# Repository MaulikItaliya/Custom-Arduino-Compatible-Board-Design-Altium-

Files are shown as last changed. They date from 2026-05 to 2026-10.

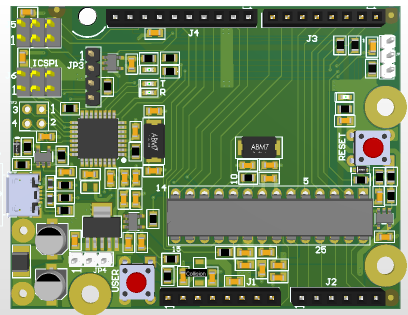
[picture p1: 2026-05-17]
!Released Files/Step 2 - Board Assembly/Variant 2 - 28Pins V1.1-5V and 3V3/3D Model - 28Pins V1.1 - 5V and 3.3V.png

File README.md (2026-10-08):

# Arduino Compatible 28-Pin Development Board

## Overview
Custom Arduino-compatible PCB designed in Altium Designer.

Features:
- ATmega328P-based design
- USB/UART programming
- 5V and 3.3V variants
- Through-hole + SMD support
- 2-layer PCB 

## Tools Used
- Altium Designer
- Gerber Generation
- Assembly Drawings
- BOM Export

## Repository Structure
/docs
/hardware
/manufacturing
/images

## Variants
### Variant 1
Fixed 5V version

### Variant 2
5V + 3.3V selectable version

## Manufacturing Files
Gerber, drill, BOM, pick-and-place, and assembly outputs included.

## Images


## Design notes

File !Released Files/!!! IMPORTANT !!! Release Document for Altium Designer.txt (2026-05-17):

Follow this procedure before releasing files. Confirm every action with your initials and date.
IF ANY CHANGES NEEDS TO BE DONE, START THE PROCEDURE FROM BEGINNING!

The procedure needs to be executed in order as defined here. Start from number 1
--------------------------------------------------------------------------------

1) Right Click on the project -> Compile PCB project
I confirm, the project compiles with no errors: 
YourIntials [15-05-2026]

2) Run Design -> Update PCB Document
I confirm, there are no differences between Schematic and PCB: 
 [15-05-2026]

3) Impedance
I confirm, I have updated and check track width/gap to match required impedance (e.g 55 OHMs): 
NA

4) Run Tools -> Polygon Pours -> Rebuild All
I confirm, all polygons have been repoured: 
 [15-05-2026]

5) Run Tools -> Design Rule Check -> Run Design Rule Check
I confirm, I have checked Design Rule Output File:
 [15-05-2026]

6) Gerber check
I confirm, I have copied and visually checked gerber files placed in \PCB Manufacturing\Gerber Output\
 [15-05-2026]

7) Other files
I confirm, I have copied and checked files placed in subdirectories:
YourIntials [DAY-MONTH-YEAR]

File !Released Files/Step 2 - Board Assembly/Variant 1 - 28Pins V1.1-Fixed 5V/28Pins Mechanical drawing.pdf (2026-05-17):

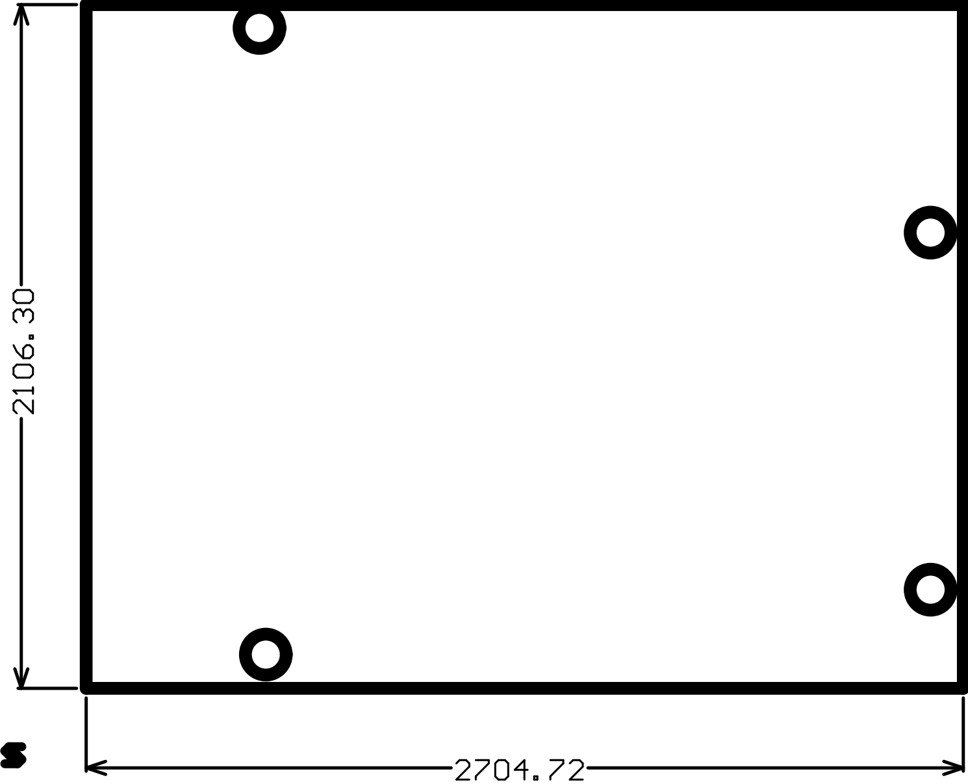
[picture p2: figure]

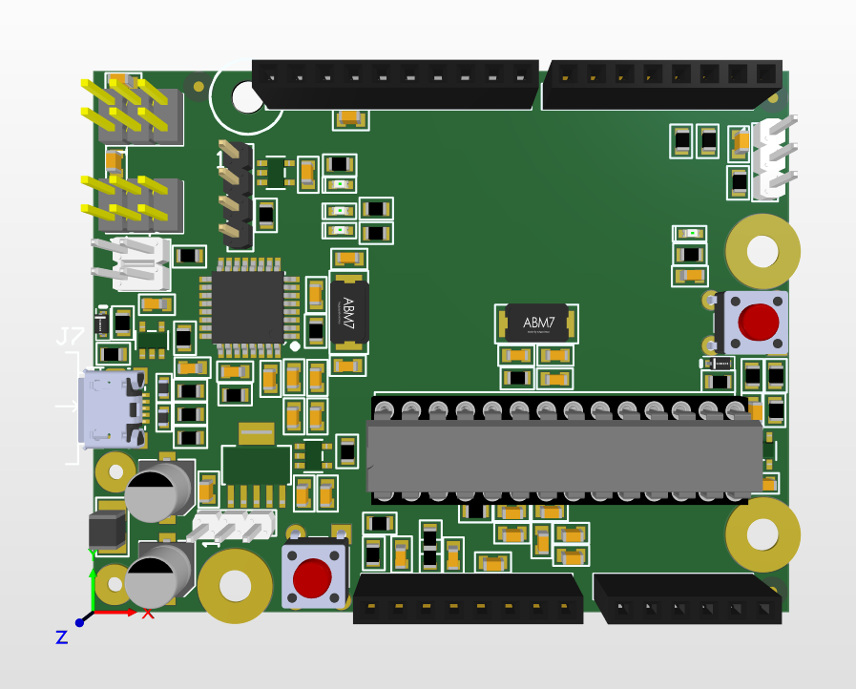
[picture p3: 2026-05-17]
images/Screenshot 2026-04-12 070946.png

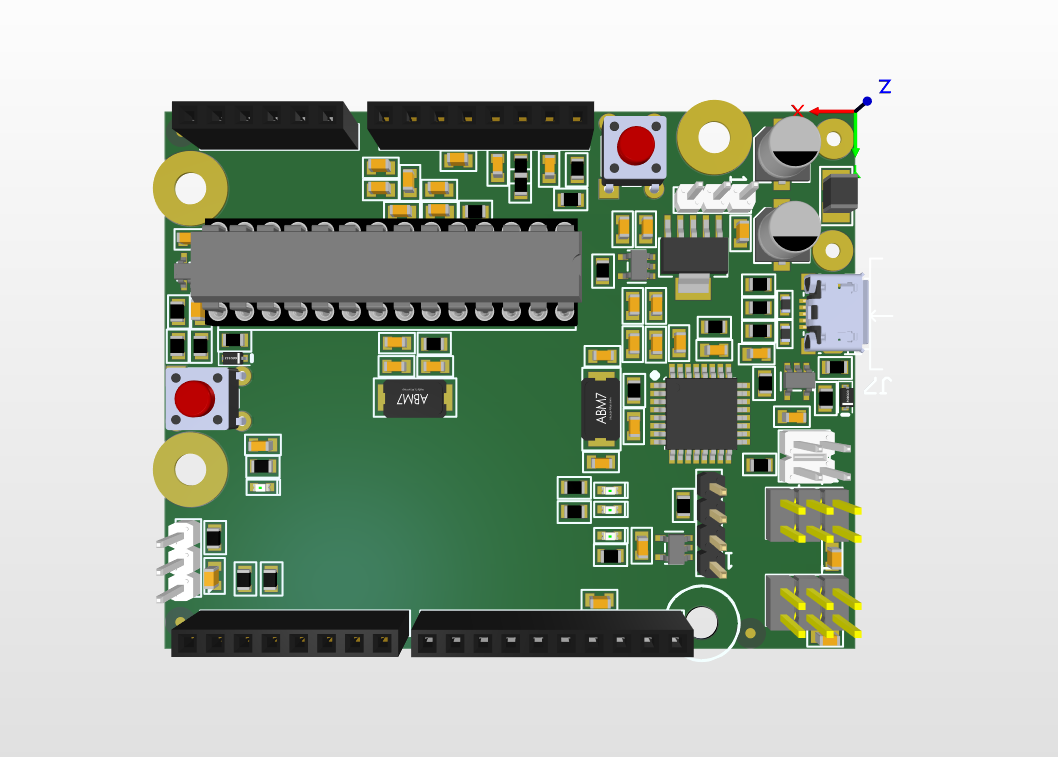
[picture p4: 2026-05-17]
images/Screenshot 2026-04-13 221038.png

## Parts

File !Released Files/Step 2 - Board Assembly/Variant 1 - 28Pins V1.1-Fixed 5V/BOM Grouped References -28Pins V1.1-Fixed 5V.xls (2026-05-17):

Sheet: Part List Report
 | Component reference list (grouped) |  |  |  | 28Pins
 | Source Data From: |  | ardino.PrjPcb |  |  | Contact: |  | Generated by:
 | Project: |  | ardino.PrjPcb
 | Variant: |  | FIXED 5V |  |  |  |  | FEDEVEL
 | Report Date: |  | 16-05-2026 | 10:37 |  |  |  | http://www.fedevel.com
 | Print Date: |  | 2026-05-16 | 10:38:30
# | Designator | Quantity | Comment | Description | #Column Name Error:' Manufacturer 1 | #Column Name Error:' Manufacturer Part Number 1 | #Column Name Error:' Package / Case | #Column Name Error:' Supplier 1 | #Column Name Error:' Supplier Part Number 1
1 | C1, C2 | 2 | 100uF/10V | Cap Aluminum Polymer 100uF 10VDC 20% (7.3 X 4.3 X 1.9mm) SMD 0.04 Ohm 3200mA 2000h 105C T/R
2 | C3, C12, C13, C19, C21, C22 | 6 | 10uF/16V | 16V 10uF X5R 卤10% 0805 Multilayer Ceramic Capacitors MLCC - SMD/SMT ROHS
3 | C4, C5, C6, C8, C11, C14, C15, C16, C17, C20, C23, C24, C26, C28, C29, C30, C31, C32, C33, C34 | 20 | 100nF | Ceramic capacitor, 100 nF, 50 V (DC), ±10 %, SMD 0805 (2012), X7R, C2012X7R1H104K085AA
4 | C7 | 1 | 1uf | 25V 1uF X5R 卤20% 0805 Multilayer Ceramic Capacitors MLCC - SMD/SMT ROHS
5 | C9, C10, C25, C27 | 4 | 18pF | Multilayer Ceramic Capacitors MLCC - SMD/SMT 50V 18pF C0G 0805 2%
6 | D1 | 1 | Green | LED Uni-Color Green 572nm Automotive 2-Pin Chip 0603(1608Metric) T/R
7 | D2, D3, D4 | 3 | Orange | LED Uni-Color Orange 610nm Automotive 2-Pin Chip 0603(1608Metric) T/R
8 | D5, D6 | 2 | BAT54HT1G | Small Signal Schottky Diode, Single, 30 V, 200 Ma, 800 Mv, 600 Ma, 150 C
9 | FB1, FB2, FB3 | 3 | MPZ2012S601AT000 | Ferrite Beads Multi-Layer Power 600Ohm 25% 100MHz 2A 100mOhm DCR 0805 T/R
10 | J1, J3 | 2 | HDR FEMALE 1x8 2.54mm | 2.54mm (0.1) Pitch SIL Vertical PC Tail Socket Assembly, selective gold + tin, 8 contacts"
11 | J2 | 1 | HDR_1x6_2.54mm | Conn Socket Strip Receptacle 6 Position 2.54mm Solder Straight Through Hole Tube
12 | J4 | 1 | M20-7821046 | Conn Socket Strip Receptacle 10 Position 2.54mm Solder Straight Through Hole Tube
13 | J5, J6 | 2 | HDR_2X3 | Conn Unshrouded Header HDR 6 POS 2.54mm Solder ST Top Entry Thru-Hole BergStik® Bag
14 | J7 | 1 | 10118193-0001LF | USB - micro B USB 2.0 Receptacle Connector 5 Position Surface Mount, Right Angle, Horizontal
15 | JP1 | 1 | HDR_1x3 | Pin Header, Board-to-Board, 2.54 mm, 1 Rows, 3 Contacts, Through Hole, FCI BergStik II 68000
16 | JP3 | 1 | HDR_x4 | Conn Unshrouded Header HDR 4 POS 2.54mm Solder ST Top Entry Thru-Hole BergStik® Bulk
17 | L1 | 1 | 2u2 / 2A | General Purpose Inductor, 2.2uH, 20%, 1 Element, Ferrite-Core, SMD, 1210
18 | Link1, Link2 | 2 | Link | 2 Position 2.54 mm Centerline Single Circuit Open Top Jumper
19 | R1 | 1 | 100k | 125Mw Thick Film Resistors 100Ppm/ 1% 100K 0805 Chip Resistor Surface Mount Rohs
20 | R2, R3, R15, R17, R22 | 5 | 560 | Fixed Resistor, Metal Glaze/thick Film, 0.125W, 560ohm, 150V, 1% +/-Tol, 100ppm/Cel, Surface Mount, 0805
21 | R4, R14, R18, R19, R20, R21 | 6 | 10k | Res Thick Film 0805 10K Ohm 1% 0.125W(1/8W) +/-100ppm/C Epoxy Pad SMD T/R
22 | R5, R6, R7, R13, R23, R24, R25 | 7 | 22R | 125mW Thick Film Resistors 150V ±100ppm/℃ ±1% 22Ω 0805 Chip Resistor - Surface Mount ROHS
23 | R8, R27 | 2 | 0 | GENERAL PURPOSE CHIP RESISTOR Metal Glaze/thick Film, 0.125W, 0ohm, Surface Mount, 0805
24 | R9, R16 | 2 | 1M | Res Thick Film 0805 1M Ohm 1% 0.125W(1/8W) ±100ppm/C Pad SMD T/R Automotive AEC-Q200
25 | R10, R11, R12 | 3 | 1k | Res Thick Film 0805 1K Ohm 1% 0.125W(1/8W) ±100ppm/C Pad SMD T/R
26 | SCKT FOR U1 | 1 | 28-DIP Socket | IC Socket, DIP28, 28 Contact(s), 2.54mm Term Pitch, 7.62mm Row Spacing, Solder
27 | SW1, SW2 | 2 | 1825910-6 | Switch Tactile OFF (ON) SPST Round Button PC Pins 0.05A 24VDC 1.57N Thru-Hole Loose
28 | U1 | 1 | ATMEGA328P-PU | Microchip - ATMEGA328P-PU - Microcontroller Mcu, 8 Bit, Atmega, 20MHZ, DIP-28
29 | U2 | 1 | ATMEGA16U2-AU | Risc Microcontroller, 8-BIT, Flash, AVR Risc Cpu, 16MHZ, Cmos, PQFP32
30 | U3 | 1 | TL1963A-33DCQR | LDO Regulator Pos 3.3V 1.5A 6-Pin(5+Tab) SOT-223 T/R
31 | U4, U5, U6, U7 | 4 | SN74AHC1G09DBVR | 1-ch, 2-input 2-V to 5.5-V high-speed (9 ns) AND gate with open-drain outputs 5-SOT-23 -55 to 125
32 | Y1, Y2 | 2 | ABM7-16.000MHZ-D2Y-T | Crystal 16MHz ±20ppm (Tol) ±30ppm (Stability) 18pF FUND 50Ohm 2-Pin Mini-CSMD T/R
33 | Z1, Z2 | 2 | CG0603MLC-05E | TVS Varistor, 8 V, 5 V, ChipGuard MLC, 20 V, 0603 [1608 Metric], Multilayer Varistor (MLV)
Approved |  |  |  |  | Notes

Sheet: Project Information
Project Full Path | D:\udemy pcb design\ardino\arduino-pcb-design\hardware\ardino.PrjPcb
Project Filename | ardino.PrjPcb
Variant Name | FIXED 5V
Data-Source Filename | ardino.PrjPcb
Data-Source Full Path | D:\udemy pcb design\ardino\arduino-pcb-design\hardware\ardino.PrjPcb
Title | ardino.PrjPcb
Total Quantity | 94
Report Time | 10:37
Report Date | 16-05-2026
Report Date & Tine | 16-05-2026 10:37
Output Name | 28Pins Component reference BOM
Output Type | BomReport
Output Generator Name | BOM
Output Generator Description | Bill of Materials

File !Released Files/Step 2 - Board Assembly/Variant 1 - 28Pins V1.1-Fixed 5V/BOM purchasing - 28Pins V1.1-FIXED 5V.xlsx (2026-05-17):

Comment | Description | Designator | Footprint | LibRef | Quantity
0 | GENERAL PURPOSE CHIP RESISTOR Metal Glaze/thick Film, 0.125W, 0ohm, Surface Mount, 0805 | R8, R27 | R0805 | RC0805JR-070RL | 2
1k | Res Thick Film 0805 1K Ohm 1% 0.125W(1/8W) ±100ppm/C Pad SMD T/R | R10, R11, R12 | R0805 | RC0805FR-101KL | 3
1M | Res Thick Film 0805 1M Ohm 1% 0.125W(1/8W) ±100ppm/C Pad SMD T/R Automotive AEC-Q200 | R9, R16 | R0805 | RV0805FR-071ML | 2
1uf | 25V 1uF X5R 卤20% 0805 Multilayer Ceramic Capacitors MLCC - SMD/SMT ROHS | C7 | C0805 | C2012X5R1E105M125AA | 1
2u2 / 2A | General Purpose Inductor, 2.2uH, 20%, 1 Element, Ferrite-Core, SMD, 1210 | L1 | C1210_Inductor | L1210R2R2MDWIT | 1
10k | Res Thick Film 0805 10K Ohm 1% 0.125W(1/8W) +/-100ppm/C Epoxy Pad SMD T/R | R4, R14, R18, R19, R20, R21 | R0805 | RC0805FR-0710KL | 6
10uF/16V | 16V 10uF X5R 卤10% 0805 Multilayer Ceramic Capacitors MLCC - SMD/SMT ROHS | C3, C12, C13, C19, C21, C22 | C0805 | C2012X5R1C106K085AC | 6
18pF | Multilayer Ceramic Capacitors MLCC - SMD/SMT 50V 18pF C0G 0805 2% | C9, C10, C25, C27 | C0805 | C0805C180G5GACTU | 4
22R | 125mW Thick Film Resistors 150V ±100ppm/℃ ±1% 22Ω 0805 Chip Resistor - Surface Mount ROHS | R5, R6, R7, R13, R23, R24, R25 | R0805 | RC0805FR-0722RL | 7
28-DIP Socket | IC Socket, DIP28, 28 Contact(s), 2.54mm Term Pitch, 7.62mm Row Spacing, Solder | SCKT FOR U1 | 28-DIP Socket | 4828-3004-CP | 1
100k | 125Mw Thick Film Resistors 100Ppm/ 1% 100K 0805 Chip Resistor Surface Mount Rohs | R1 | R0805 | RC0805FR-07100KL | 1
100nF | Ceramic capacitor, 100 nF, 50 V (DC), ±10 %, SMD 0805 (2012), X7R, C2012X7R1H104K085AA | C4, C5, C6, C8, C11, C14, C15, C16, C17, C20, C23, C24, C26, C28, C29, C30, C31, C32, C33, C34 | C0805 | C2012X7R1H104K085AA | 20
100uF/10V | Cap Aluminum Polymer 100uF 10VDC 20% (7.3 X 4.3 X 1.9mm) SMD 0.04 Ohm 3200mA 2000h 105C T/R | C1, C2 | C_Aluminium_c_size | EEF-CX1A101R | 2
560 | Fixed Resistor, Metal Glaze/thick Film, 0.125W, 560ohm, 150V, 1% +/-Tol, 100ppm/Cel, Surface Mount, 0805 | R2, R3, R15, R17, R22 | R0805 | AR0805FR-07560RL | 5
1825910-6 | Switch Tactile OFF (ON) SPST Round Button PC Pins 0.05A 24VDC 1.57N Thru-Hole Loose | SW1, SW2 | 1825910-6 | 1825910-6 | 2
10118193-0001LF | USB - micro B USB 2.0 Receptacle Connector 5 Position Surface Mount, Right Angle, Horizontal | J7 | 10118193 | 10118193-0001LF | 1
ABM7-16.000MHZ-D2Y-T | Crystal 16MHz ±20ppm (Tol) ±30ppm (Stability) 18pF FUND 50Ohm 2-Pin Mini-CSMD T/R | Y1, Y2 | ABM7_v1_1_BIG | ABM7-16.000MHZ-D2Y-T | 2
ATMEGA16U2-AU | Risc Microcontroller, 8-BIT, Flash, AVR Risc Cpu, 16MHZ, Cmos, PQFP32 | U2 | TQFP32 | ATMEGA16U2-AU | 1
ATMEGA328P-PU | Microchip - ATMEGA328P-PU - Microcontroller Mcu, 8 Bit, Atmega, 20MHZ, DIP-28 | U1 | 28_DIP_7.62mm | ATMEGA328P-PU | 1
BAT54HT1G | Small Signal Schottky Diode, Single, 30 V, 200 Ma, 800 Mv, 600 Ma, 150 C | D5, D6 | SOD323 | BAT54HT1G | 2
CG0603MLC-05E | TVS Varistor, 8 V, 5 V, ChipGuard MLC, 20 V, 0603 [1608 Metric], Multilayer Varistor (MLV) | Z1, Z2 | R0603 | CG0603MLC-05E | 2
Green | LED Uni-Color Green 572nm Automotive 2-Pin Chip 0603(1608Metric) T/R | D1 | LED_0603 | LG L29K-F2J1-24-0-2-R18-Z | 1
HDR FEMALE 1x8 2.54mm | 2.54mm (0.1) Pitch SIL Vertical PC Tail Socket Assembly, selective gold + tin, 8 contacts" | J1, J3 | Header_1x8_2.54mm | M20-7820842 | 2
HDR_1x3 | Pin Header, Board-to-Board, 2.54 mm, 1 Rows, 3 Contacts, Through Hole, FCI BergStik II 68000 | JP1 | Header_1x3_2.54mm | 68000-103HLF | 1
HDR_1x6_2.54mm | Conn Socket Strip Receptacle 6 Position 2.54mm Solder Straight Through Hole Tube | J2 | Header_1x6_2.54mm | M20-7820646 | 1
HDR_2X3 | Conn Unshrouded Header HDR 6 POS 2.54mm Solder ST Top Entry Thru-Hole BergStik® Bag | J5, J6 | HDR_2x3_2.54mm | 67997-106HLF | 2
HDR_x4 | Conn Unshrouded Header HDR 4 POS 2.54mm Solder ST Top Entry Thru-Hole BergStik® Bulk | JP3 | Header_1x4_2.54mm | 68000-204HLF | 1
Link | 2 Position 2.54 mm Centerline Single Circuit Open Top Jumper | Link1, Link2 |  | QPC02SXGN-RC | 2
M20-7821046 | Conn Socket Strip Receptacle 10 Position 2.54mm Solder Straight Through Hole Tube | J4 | Header_1x10_2.54mm | M20-7821046 | 1
MPZ2012S601AT000 | Ferrite Beads Multi-Layer Power 600Ohm 25% 100MHz 2A 100mOhm DCR 0805 T/R | FB1, FB2, FB3 | C0805 | MPZ2012S601AT000 | 3
Orange | LED Uni-Color Orange 610nm Automotive 2-Pin Chip 0603(1608Metric) T/R | D2, D3, D4 | LED_0603 | LO L29K-H2K1-24-0-2-R18-Z | 3
SN74AHC1G09DBVR | 1-ch, 2-input 2-V to 5.5-V high-speed (9 ns) AND gate with open-drain outputs 5-SOT-23 -55 to 125 | U4, U5, U6, U7 | DBV_SOT_23_5 | SN74AHC1G09DBVR | 4
TL1963A-33DCQR | LDO Regulator Pos 3.3V 1.5A 6-Pin(5+Tab) SOT-223 T/R | U3 | DCQ(R-PDSo-G6) | TL1963A-33DCQR | 1

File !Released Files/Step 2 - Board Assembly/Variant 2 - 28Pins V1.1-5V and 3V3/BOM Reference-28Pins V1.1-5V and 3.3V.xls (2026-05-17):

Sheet: Part List Report
 | Component reference list |  |  | 28Pins
 |  | Source Data From: | ardino.PrjPcb |  | Contact: |  | Generated by:
 |  | Project: | ardino.PrjPcb
 |  | Variant: | 5V/3V3 |  |  |  | FEDEVEL
 | Report Date: | 16-05-2026 | 10:32 |  |  |  | http://www.fedevel.com
 | Print Date: | 2026-05-16 | 10:32:44
# | Designator | Comment | Description | #Column Name Error:' Manufacturer 1 | #Column Name Error:' Manufacturer Part Number 1 | #Column Name Error:' Package / Case | #Column Name Error:' Supplier 1 | #Column Name Error:' Supplier Part Number 1
1 | C1 | 100uF/10V | Cap Aluminum Polymer 100uF 10VDC 20% (7.3 X 4.3 X 1.9mm) SMD 0.04 Ohm 3200mA 2000h 105C T/R
2 | C2 | 100uF/10V | Cap Aluminum Polymer 100uF 10VDC 20% (7.3 X 4.3 X 1.9mm) SMD 0.04 Ohm 3200mA 2000h 105C T/R
3 | C3 | 10uF/16V | 16V 10uF X5R 卤10% 0805 Multilayer Ceramic Capacitors MLCC - SMD/SMT ROHS
4 | C4 | 100nF | Ceramic capacitor, 100 nF, 50 V (DC), ±10 %, SMD 0805 (2012), X7R, C2012X7R1H104K085AA
5 | C5 | 100nF | Ceramic capacitor, 100 nF, 50 V (DC), ±10 %, SMD 0805 (2012), X7R, C2012X7R1H104K085AA
6 | C6 | 100nF | Ceramic capacitor, 100 nF, 50 V (DC), ±10 %, SMD 0805 (2012), X7R, C2012X7R1H104K085AA
7 | C7 | 1uf | 25V 1uF X5R 卤20% 0805 Multilayer Ceramic Capacitors MLCC - SMD/SMT ROHS
8 | C8 | 100nF | Ceramic capacitor, 100 nF, 50 V (DC), ±10 %, SMD 0805 (2012), X7R, C2012X7R1H104K085AA
9 | C9 | 18pF | Multilayer Ceramic Capacitors MLCC - SMD/SMT 50V 18pF C0G 0805 2%
10 | C10 | 18pF | Multilayer Ceramic Capacitors MLCC - SMD/SMT 50V 18pF C0G 0805 2%
11 | C11 | 100nF | Ceramic capacitor, 100 nF, 50 V (DC), ±10 %, SMD 0805 (2012), X7R, C2012X7R1H104K085AA
12 | C12 | 10uF/16V | 16V 10uF X5R 卤10% 0805 Multilayer Ceramic Capacitors MLCC - SMD/SMT ROHS
13 | C13 | 10uF/16V | 16V 10uF X5R 卤10% 0805 Multilayer Ceramic Capacitors MLCC - SMD/SMT ROHS
14 | C14 | 100nF | Ceramic capacitor, 100 nF, 50 V (DC), ±10 %, SMD 0805 (2012), X7R, C2012X7R1H104K085AA
15 | C15 | 100nF | Ceramic capacitor, 100 nF, 50 V (DC), ±10 %, SMD 0805 (2012), X7R, C2012X7R1H104K085AA
16 | C16 | 100nF | Ceramic capacitor, 100 nF, 50 V (DC), ±10 %, SMD 0805 (2012), X7R, C2012X7R1H104K085AA
17 | C17 | 100nF | Ceramic capacitor, 100 nF, 50 V (DC), ±10 %, SMD 0805 (2012), X7R, C2012X7R1H104K085AA
18 | C19 | 10uF/16V | 16V 10uF X5R 卤10% 0805 Multilayer Ceramic Capacitors MLCC - SMD/SMT ROHS
19 | C20 | 100nF | Ceramic capacitor, 100 nF, 50 V (DC), ±10 %, SMD 0805 (2012), X7R, C2012X7R1H104K085AA
20 | C21 | 10uF/16V | 16V 10uF X5R 卤10% 0805 Multilayer Ceramic Capacitors MLCC - SMD/SMT ROHS
21 | C22 | 10uF/16V | 16V 10uF X5R 卤10% 0805 Multilayer Ceramic Capacitors MLCC - SMD/SMT ROHS
22 | C23 | 100nF | Ceramic capacitor, 100 nF, 50 V (DC), ±10 %, SMD 0805 (2012), X7R, C2012X7R1H104K085AA
23 | C24 | 100nF | Ceramic capacitor, 100 nF, 50 V (DC), ±10 %, SMD 0805 (2012), X7R, C2012X7R1H104K085AA
24 | C25 | 18pF | Multilayer Ceramic Capacitors MLCC - SMD/SMT 50V 18pF C0G 0805 2%
25 | C26 | 100nF | Ceramic capacitor, 100 nF, 50 V (DC), ±10 %, SMD 0805 (2012), X7R, C2012X7R1H104K085AA
26 | C27 | 18pF | Multilayer Ceramic Capacitors MLCC - SMD/SMT 50V 18pF C0G 0805 2%
27 | C28 | 100nF | Ceramic capacitor, 100 nF, 50 V (DC), ±10 %, SMD 0805 (2012), X7R, C2012X7R1H104K085AA
28 | C29 | 100nF | Ceramic capacitor, 100 nF, 50 V (DC), ±10 %, SMD 0805 (2012), X7R, C2012X7R1H104K085AA
29 | C30 | 100nF | Ceramic capacitor, 100 nF, 50 V (DC), ±10 %, SMD 0805 (2012), X7R, C2012X7R1H104K085AA
30 | C31 | 100nF | Ceramic capacitor, 100 nF, 50 V (DC), ±10 %, SMD 0805 (2012), X7R, C2012X7R1H104K085AA
31 | C32 | 100nF | Ceramic capacitor, 100 nF, 50 V (DC), ±10 %, SMD 0805 (2012), X7R, C2012X7R1H104K085AA
32 | C33 | 100nF | Ceramic capacitor, 100 nF, 50 V (DC), ±10 %, SMD 0805 (2012), X7R, C2012X7R1H104K085AA
33 | C34 | 100nF | Ceramic capacitor, 100 nF, 50 V (DC), ±10 %, SMD 0805 (2012), X7R, C2012X7R1H104K085AA
34 | D1 | Green | LED Uni-Color Green 572nm Automotive 2-Pin Chip 0603(1608Metric) T/R
35 | D2 | Orange | LED Uni-Color Orange 610nm Automotive 2-Pin Chip 0603(1608Metric) T/R
36 | D3 | Orange | LED Uni-Color Orange 610nm Automotive 2-Pin Chip 0603(1608Metric) T/R
37 | D4 | Orange | LED Uni-Color Orange 610nm Automotive 2-Pin Chip 0603(1608Metric) T/R
38 | D5 | BAT54HT1G | Small Signal Schottky Diode, Single, 30 V, 200 Ma, 800 Mv, 600 Ma, 150 C
39 | D6 | BAT54HT1G | Small Signal Schottky Diode, Single, 30 V, 200 Ma, 800 Mv, 600 Ma, 150 C
40 | FB1 | MPZ2012S601AT000 | Ferrite Beads Multi-Layer Power 600Ohm 25% 100MHz 2A 100mOhm DCR 0805 T/R
41 | FB2 | MPZ2012S601AT000 | Ferrite Beads Multi-Layer Power 600Ohm 25% 100MHz 2A 100mOhm DCR 0805 T/R
42 | FB3 | MPZ2012S601AT000 | Ferrite Beads Multi-Layer Power 600Ohm 25% 100MHz 2A 100mOhm DCR 0805 T/R
43 | J1 | HDR FEMALE 1x8 2.54mm | 2.54mm (0.1) Pitch SIL Vertical PC Tail Socket Assembly, selective gold + tin, 8 contacts"
44 | J2 | HDR_1x6_2.54mm | Conn Socket Strip Receptacle 6 Position 2.54mm Solder Straight Through Hole Tube
45 | J3 | HDR FEMALE 1x8 2.54mm | 2.54mm (0.1) Pitch SIL Vertical PC Tail Socket Assembly, selective gold + tin, 8 contacts"
46 | J4 | M20-7821046 | Conn Socket Strip Receptacle 10 Position 2.54mm Solder Straight Through Hole Tube
47 | J5 | HDR_2X3 | Conn Unshrouded Header HDR 6 POS 2.54mm Solder ST Top Entry Thru-Hole BergStik® Bag
48 | J6 | HDR_2X3 | Conn Unshrouded Header HDR 6 POS 2.54mm Solder ST Top Entry Thru-Hole BergStik® Bag
49 | J7 | 10118193-0001LF | USB - micro B USB 2.0 Receptacle Connector 5 Position Surface Mount, Right Angle, Horizontal
50 | JP1 | HDR_1x3 | Pin Header, Board-to-Board, 2.54 mm, 1 Rows, 3 Contacts, Through Hole, FCI BergStik II 68000
51 | JP3 | HDR_x4 | Conn Unshrouded Header HDR 4 POS 2.54mm Solder ST Top Entry Thru-Hole BergStik® Bulk
52 | JP4 | HDR_1x3 | Pin Header, Board-to-Board, 2.54 mm, 1 Rows, 3 Contacts, Through Hole, FCI BergStik II 68000
53 | L1 | 2u2 / 2A | General Purpose Inductor, 2.2uH, 20%, 1 Element, Ferrite-Core, SMD, 1210
54 | Link1 | Link | 2 Position 2.54 mm Centerline Single Circuit Open Top Jumper
55 | Link2 | Link | 2 Position 2.54 mm Centerline Single Circuit Open Top Jumper
56 | Link3 | Link | 2 Position 2.54 mm Centerline Single Circuit Open Top Jumper
57 | R1 | 100k | 125Mw Thick Film Resistors 100Ppm/ 1% 100K 0805 Chip Resistor Surface Mount Rohs
58 | R2 | 560 | Fixed Resistor, Metal Glaze/thick Film, 0.125W, 560ohm, 150V, 1% +/-Tol, 100ppm/Cel, Surface Mount, 0805
59 | R3 | 560 | Fixed Resistor, Metal Glaze/thick Film, 0.125W, 560ohm, 150V, 1% +/-Tol, 100ppm/Cel, Surface Mount, 0805
60 | R4 | 10k | Res Thick Film 0805 10K Ohm 1% 0.125W(1/8W) +/-100ppm/C Epoxy Pad SMD T/R
61 | R5 | 22R | 125mW Thick Film Resistors 150V ±100ppm/℃ ±1% 22Ω 0805 Chip Resistor - Surface Mount ROHS
62 | R6 | 22R | 125mW Thick Film Resistors 150V ±100ppm/℃ ±1% 22Ω 0805 Chip Resistor - Surface Mount ROHS
63 | R7 | 22R | 125mW Thick Film Resistors 150V ±100ppm/℃ ±1% 22Ω 0805 Chip Resistor - Surface Mount ROHS
64 | R8 | 0 | GENERAL PURPOSE CHIP RESISTOR Metal Glaze/thick Film, 0.125W, 0ohm, Surface Mount, 0805
65 | R9 | 1M | Res Thick Film 0805 1M Ohm 1% 0.125W(1/8W) ±100ppm/C Pad SMD T/R Automotive AEC-Q200
66 | R10 | 1k | Res Thick Film 0805 1K Ohm 1% 0.125W(1/8W) ±100ppm/C Pad SMD T/R
67 | R11 | 1k | Res Thick Film 0805 1K Ohm 1% 0.125W(1/8W) ±100ppm/C Pad SMD T/R
68 | R12 | 1k | Res Thick Film 0805 1K Ohm 1% 0.125W(1/8W) ±100ppm/C Pad SMD T/R
69 | R13 | 22R | 125mW Thick Film Resistors 150V ±100ppm/℃ ±1% 22Ω 0805 Chip Resistor - Surface Mount ROHS
70 | R14 | 10k | Res Thick Film 0805 10K Ohm 1% 0.125W(1/8W) +/-100ppm/C Epoxy Pad SMD T/R
71 | R15 | 560 | Fixed Resistor, Metal Glaze/thick Film, 0.125W, 560ohm, 150V, 1% +/-Tol, 100ppm/Cel, Surface Mount, 0805
72 | R16 | 1M | Res Thick Film 0805 1M Ohm 1% 0.125W(1/8W) ±100ppm/C Pad SMD T/R Automotive AEC-Q200
73 | R17 | 560 | Fixed Resistor, Metal Glaze/thick Film, 0.125W, 560ohm, 150V, 1% +/-Tol, 100ppm/Cel, Surface Mount, 0805
74 | R18 | 10k | Res Thick Film 0805 10K Ohm 1% 0.125W(1/8W) +/-100ppm/C Epoxy Pad SMD T/R
75 | R19 | 10k | Res Thick Film 0805 10K Ohm 1% 0.125W(1/8W) +/-100ppm/C Epoxy Pad SMD T/R
76 | R20 | 10k | Res Thick Film 0805 10K Ohm 1% 0.125W(1/8W) +/-100ppm/C Epoxy Pad SMD T/R
77 | R21 | 10k | Res Thick Film 0805 10K Ohm 1% 0.125W(1/8W) +/-100ppm/C Epoxy Pad SMD T/R
78 | R22 | 560 | Fixed Resistor, Metal Glaze/thick Film, 0.125W, 560ohm, 150V, 1% +/-Tol, 100ppm/Cel, Surface Mount, 0805
79 | R23 | 22R | 125mW Thick Film Resistors 150V ±100ppm/℃ ±1% 22Ω 0805 Chip Resistor - Surface Mount ROHS
80 | R24 | 22R | 125mW Thick Film Resistors 150V ±100ppm/℃ ±1% 22Ω 0805 Chip Resistor - Surface Mount ROHS
81 | R25 | 22R | 125mW Thick Film Resistors 150V ±100ppm/℃ ±1% 22Ω 0805 Chip Resistor - Surface Mount ROHS
82 | SCKT FOR U1 | 28-DIP Socket | IC Socket, DIP28, 28 Contact(s), 2.54mm Term Pitch, 7.62mm Row Spacing, Solder
83 | SW1 | 1825910-6 | Switch Tactile OFF (ON) SPST Round Button PC Pins 0.05A 24VDC 1.57N Thru-Hole Loose
84 | SW2 | 1825910-6 | Switch Tactile OFF (ON) SPST Round Button PC Pins 0.05A 24VDC 1.57N Thru-Hole Loose
85 | U1 | ATMEGA328P-PU | Microchip - ATMEGA328P-PU - Microcontroller Mcu, 8 Bit, Atmega, 20MHZ, DIP-28
86 | U2 | ATMEGA16U2-AU | Risc Microcontroller, 8-BIT, Flash, AVR Risc Cpu, 16MHZ, Cmos, PQFP32
87 | U3 | TL1963A-33DCQR | LDO Regulator Pos 3.3V 1.5A 6-Pin(5+Tab) SOT-223 T/R
88 | U4 | SN74AHC1G09DBVR | 1-ch, 2-input 2-V to 5.5-V high-speed (9 ns) AND gate with open-drain outputs 5-SOT-23 -55 to 125
89 | U5 | SN74AHC1G09DBVR | 1-ch, 2-input 2-V to 5.5-V high-speed (9 ns) AND gate with open-drain outputs 5-SOT-23 -55 to 125
90 | U6 | SN74AHC1G09DBVR | 1-ch, 2-input 2-V to 5.5-V high-speed (9 ns) AND gate with open-drain outputs 5-SOT-23 -55 to 125
91 | U7 | SN74AHC1G09DBVR | 1-ch, 2-input 2-V to 5.5-V high-speed (9 ns) AND gate with open-drain outputs 5-SOT-23 -55 to 125
92 | Y1 | ABM7-10.000MHZ-D2Y-T | Crystal 10MHz ±20ppm (Tol) ±30ppm (Stability) 18pF FUND 80Ohm 2-Pin Mini-CSMD T/R
93 | Y2 | ABM7-8.000MHZ-D2Y-T_1 | Crystal 8MHz ±20ppm (Tol) ±30ppm (Stability) 18pF FUND 100Ohm 2-Pin Mini-CSMD T/R
94 | Z1 | CG0603MLC-05E | TVS Varistor, 8 V, 5 V, ChipGuard MLC, 20 V, 0603 [1608 Metric], Multilayer Varistor (MLV)
95 | Z2 | CG0603MLC-05E | TVS Varistor, 8 V, 5 V, ChipGuard MLC, 20 V, 0603 [1608 Metric], Multilayer Varistor (MLV)
Approved |  |  |  | Notes

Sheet: Project Information
Project Full Path | D:\udemy pcb design\ardino\arduino-pcb-design\hardware\ardino.PrjPcb
Project Filename | ardino.PrjPcb
Variant Name | 5V/3V3
Data-Source Filename | ardino.PrjPcb
Data-Source Full Path | D:\udemy pcb design\ardino\arduino-pcb-design\hardware\ardino.PrjPcb
Title | ardino.PrjPcb
Total Quantity | 95
Report Time | 10:32
Report Date | 16-05-2026
Report Date & Tine | 16-05-2026 10:32
Output Name | 28Pins Component reference BOM
Output Type | BomReport
Output Generator Name | BOM
Output Generator Description | Bill of Materials

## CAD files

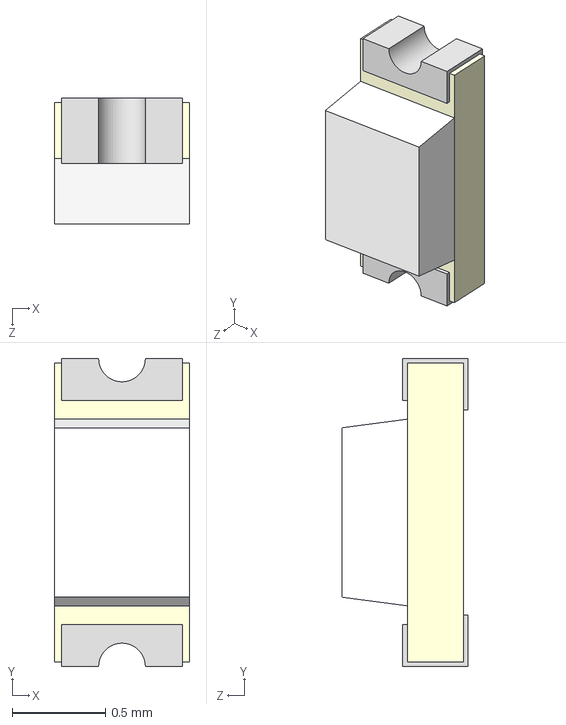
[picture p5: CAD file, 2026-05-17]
arduino-pcb-design/hardware/Footprint 3d/User Library-LED SMD0603.step
0.725 x 1.65 x 0.675 mm

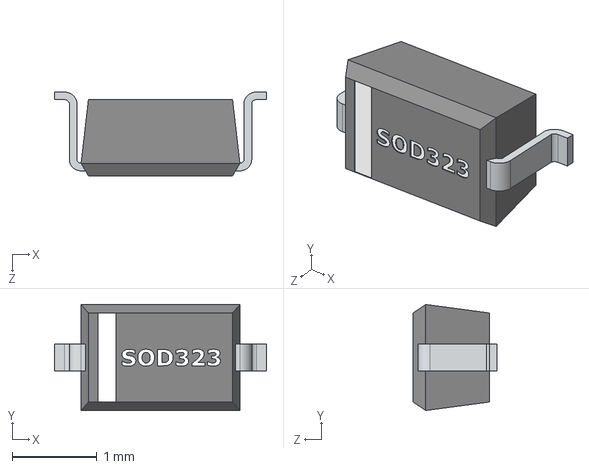
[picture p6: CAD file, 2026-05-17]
arduino-pcb-design/hardware/Footprint 3d/User Library-SOD323.step
2.50 x 1.25 x 0.99 mm

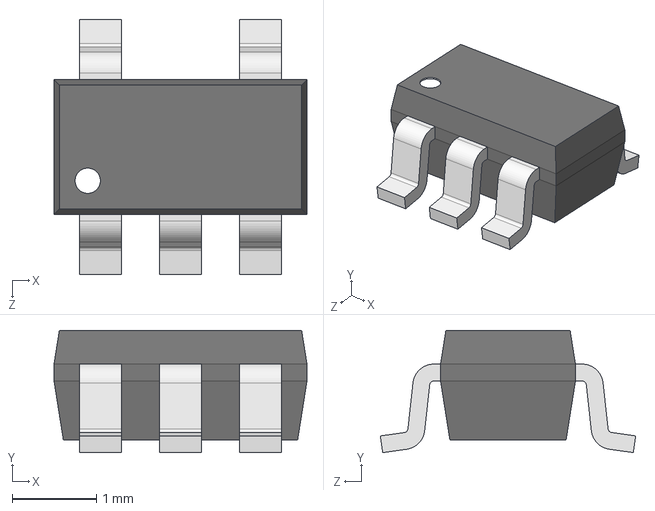
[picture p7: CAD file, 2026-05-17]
arduino-pcb-design/hardware/Footprint 3d/User Library-TPS560200DBV.step
3.00 x 1.45 x 3.03 mm

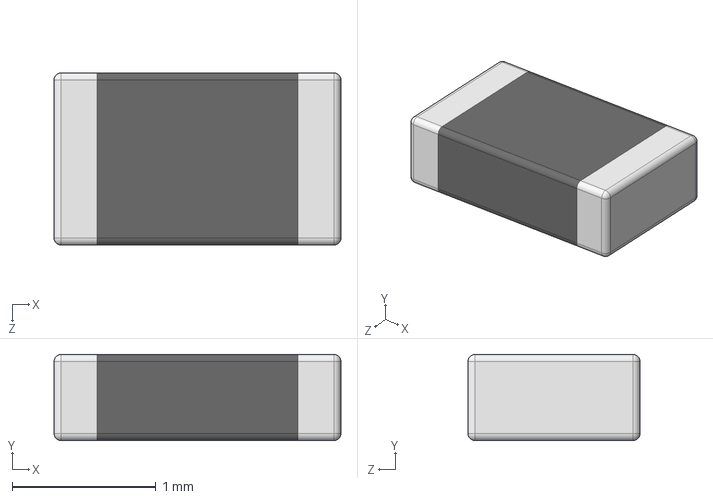
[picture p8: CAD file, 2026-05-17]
arduino-pcb-design/hardware/Footprint 3d/RESC2012X60N EIA 0805.step
2.00 x 0.6 x 1.20 mm

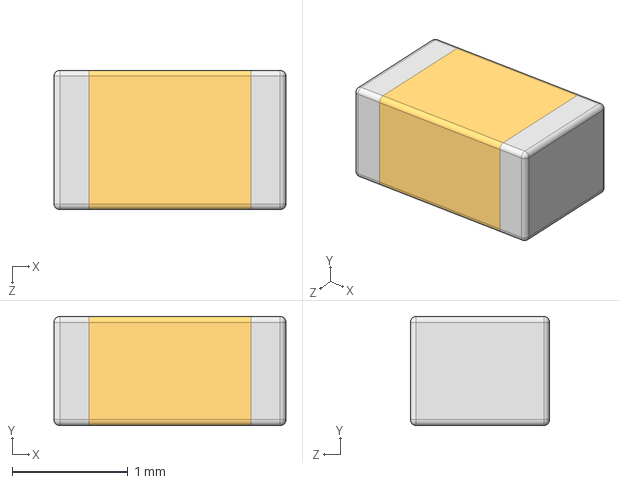
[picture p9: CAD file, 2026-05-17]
arduino-pcb-design/hardware/Footprint 3d/CAPC2012X94N EIA 0805.step
2.00 x 0.94 x 1.20 mm

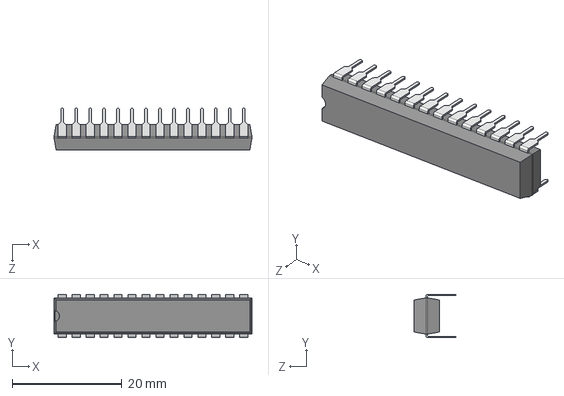
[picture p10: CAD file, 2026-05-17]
arduino-pcb-design/hardware/Footprint 3d/User Library-DIP28-300.step
36.0 x 7.87 x 7.57 mm

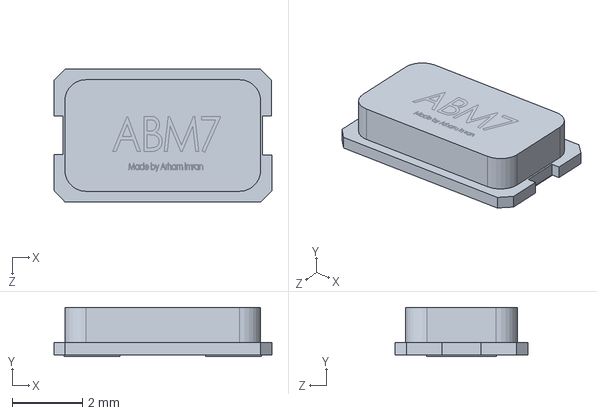
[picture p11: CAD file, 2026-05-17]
arduino-pcb-design/hardware/Footprint 3d/User Library-ABM7-1.SLDPRT
6.21 x 1.40 x 3.80 mm

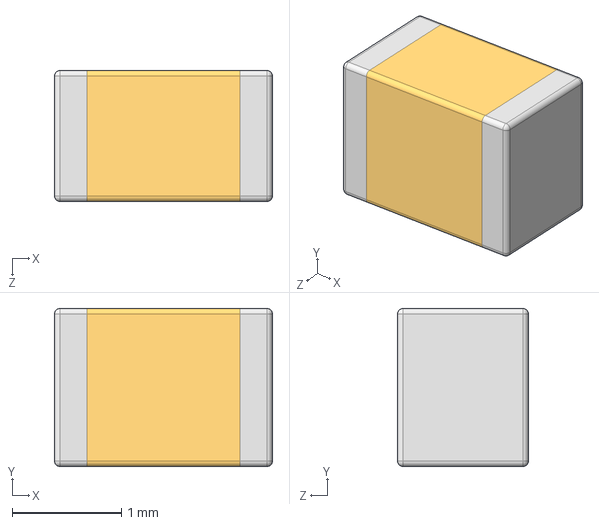
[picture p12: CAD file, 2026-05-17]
arduino-pcb-design/hardware/Footprint 3d/CAPC2012X145N EIA 0805.step
2.00 x 1.45 x 1.20 mm

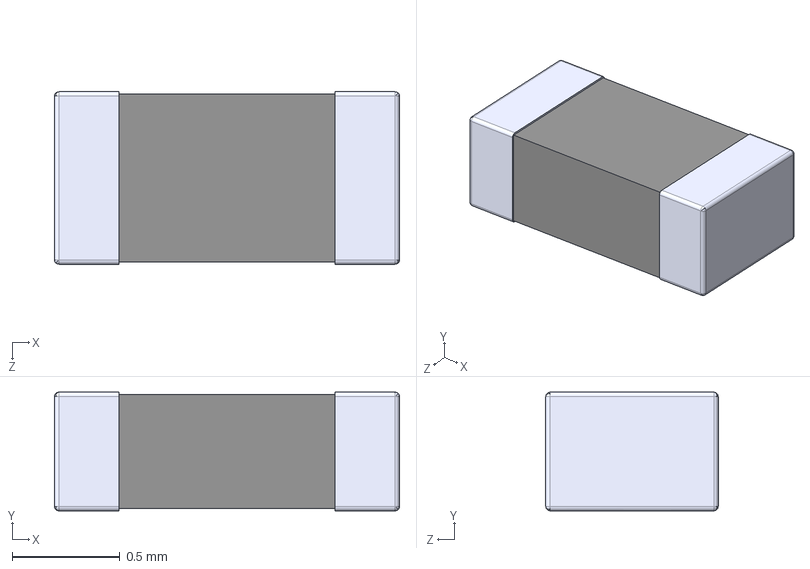
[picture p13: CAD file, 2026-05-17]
arduino-pcb-design/hardware/Footprint 3d/CG0603MLC-05E--3DModel-STEP-1.STEP
1.60 x 0.55 x 0.8 mm

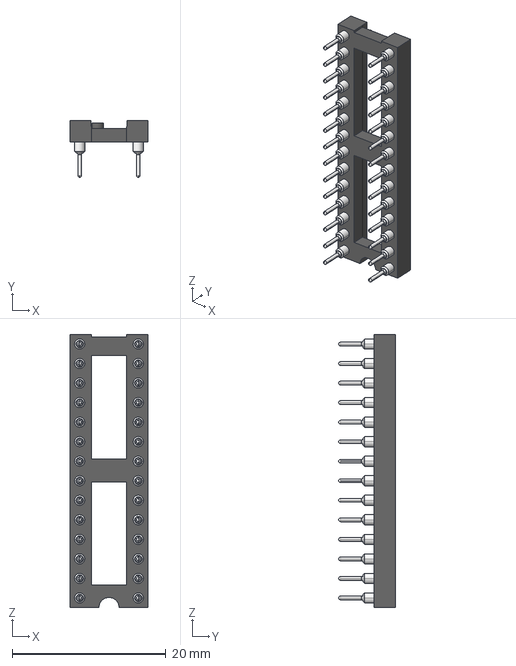
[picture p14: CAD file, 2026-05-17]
arduino-pcb-design/hardware/Footprint 3d/dil_socket.stp
10.1 x 7.37 x 35.5 mm

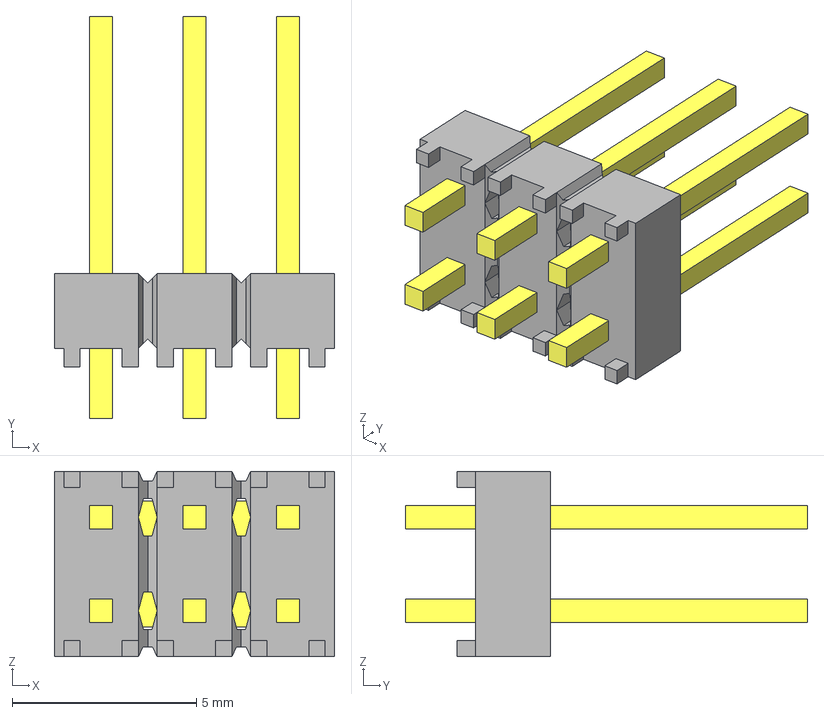
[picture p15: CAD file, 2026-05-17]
arduino-pcb-design/hardware/Footprint 3d/HMTSW-103-07-L-D-275.stp
7.62 x 10.9 x 5.03 mm
HMTSW-103-07-L-D-275_body
HMTSW-103-07-D-275

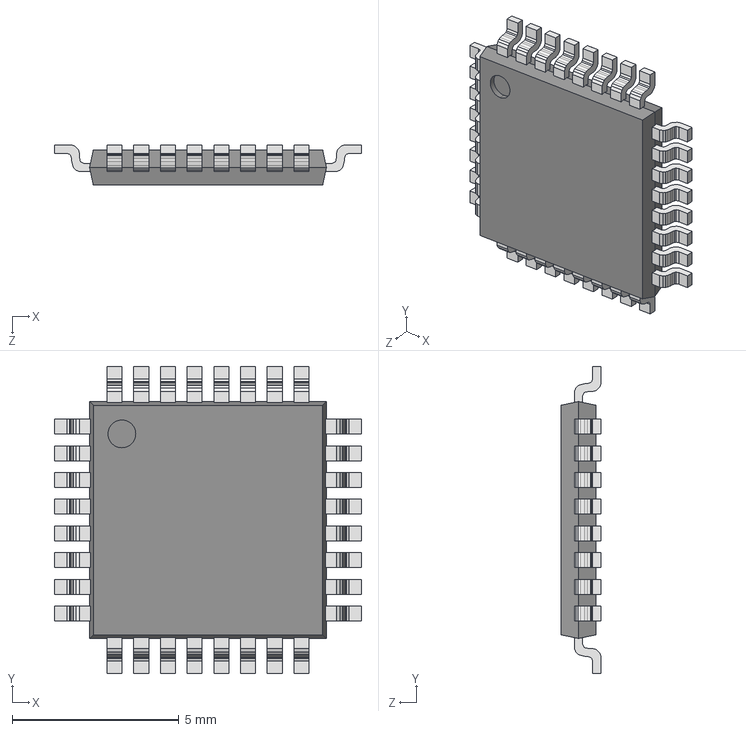
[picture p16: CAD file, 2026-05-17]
arduino-pcb-design/hardware/Footprint 3d/User Library-tqfp32.step
9.20 x 9.20 x 1.20 mm

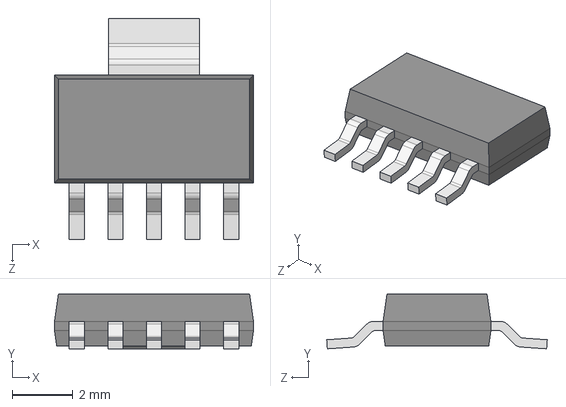
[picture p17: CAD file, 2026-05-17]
arduino-pcb-design/hardware/Footprint 3d/User Library-TPS73701DCQ.step
6.55 x 1.80 x 7.26 mm

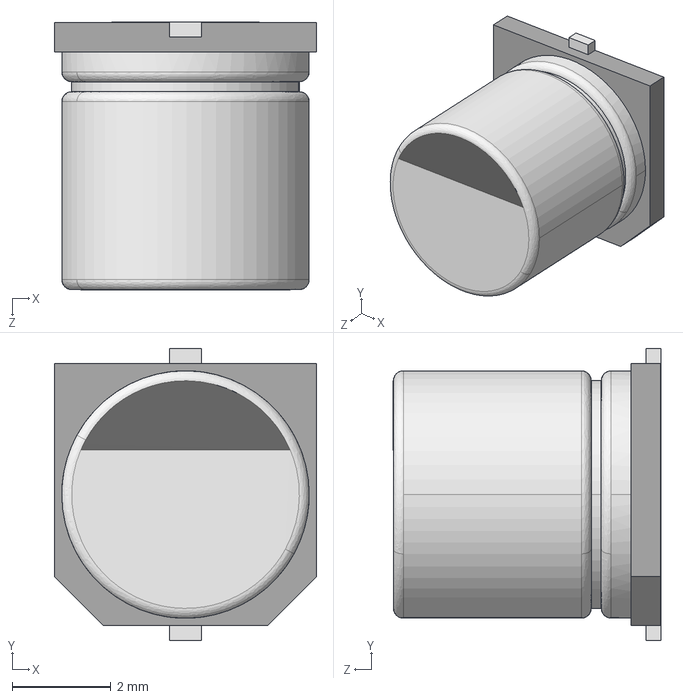
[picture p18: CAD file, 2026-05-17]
arduino-pcb-design/hardware/Footprint 3d/User Library-capacitor size C.step
5.30 x 5.90 x 5.41 mm

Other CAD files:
arduino-pcb-design/hardware/Footprint 3d/1825910-6--3DModel-STEP-418109.STEP
arduino-pcb-design/hardware/Footprint 3d/m20-7820842.stp
arduino-pcb-design/hardware/Footprint 3d/68000-103HLF--3DModel-STEP-533217.STEP
arduino-pcb-design/hardware/Footprint 3d/10118193-0001LF--3DModel-STEP-56544.STEP
arduino-pcb-design/hardware/Footprint 3d/68000-204HLF--3DModel-STEP-56544.STEP
arduino-pcb-design/hardware/Footprint 3d/m20-7820646.stp
arduino-pcb-design/hardware/Footprint 3d/m20-7821046_1x10.stp
arduino-pcb-design/hardware/Footprint 3d/s10129381-X04003XLF.stp

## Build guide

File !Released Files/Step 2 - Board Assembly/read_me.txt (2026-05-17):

Place following files here:

- Mechanical Drawing (Board dimensions, holes position, ..)
- TOP and BOTTOM Assembly Drawing (Component position with Reference Designator)
- TOP and BOTTOM VIEW (shows board outline, assembly layer, TOP + BOTTOM layers)
- Bill of Materials (grouped by component type)
- Component reference BOM (each component on one line: Designator, Description, Manufacturer 1,
  Manufacturer, Part Number 1, Package / Case, Supplier 1, Supplier Part Number 1)
- Component reference BOM (as above) grouped by component type.
- Pick and Place
- TOP and BOTTOM Layer + TOP and BOTTOM Paste Gerber Files (for stencil - if panel is done in a PCB house, ask them later for the top/bottom layers and paste for the panel)
- PDF 3D Model

!!! BE AWARE !!! If you use a VARIANT were you replace a component by other component,
THIS WILL NOT BE REFLECTED IN ASSEMBLY DRAWING and component will look like not fitted.
This may be a bug in Altium 14.3. Use a TEMP Schematic to generate the ASM DRWG. SAME
FOR PICK & PLACE!!

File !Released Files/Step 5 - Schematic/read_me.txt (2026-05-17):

Update Schematic Cover Page to RELEASED DD-MMM-YYYY
Place here PDF version of schematic, if possible one for each BOM variant.

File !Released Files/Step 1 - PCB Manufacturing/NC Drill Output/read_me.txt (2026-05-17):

Place here drill files and documents which explain it (e.g. for HDI PCB you can put here pdf showing drills for each layer pair)

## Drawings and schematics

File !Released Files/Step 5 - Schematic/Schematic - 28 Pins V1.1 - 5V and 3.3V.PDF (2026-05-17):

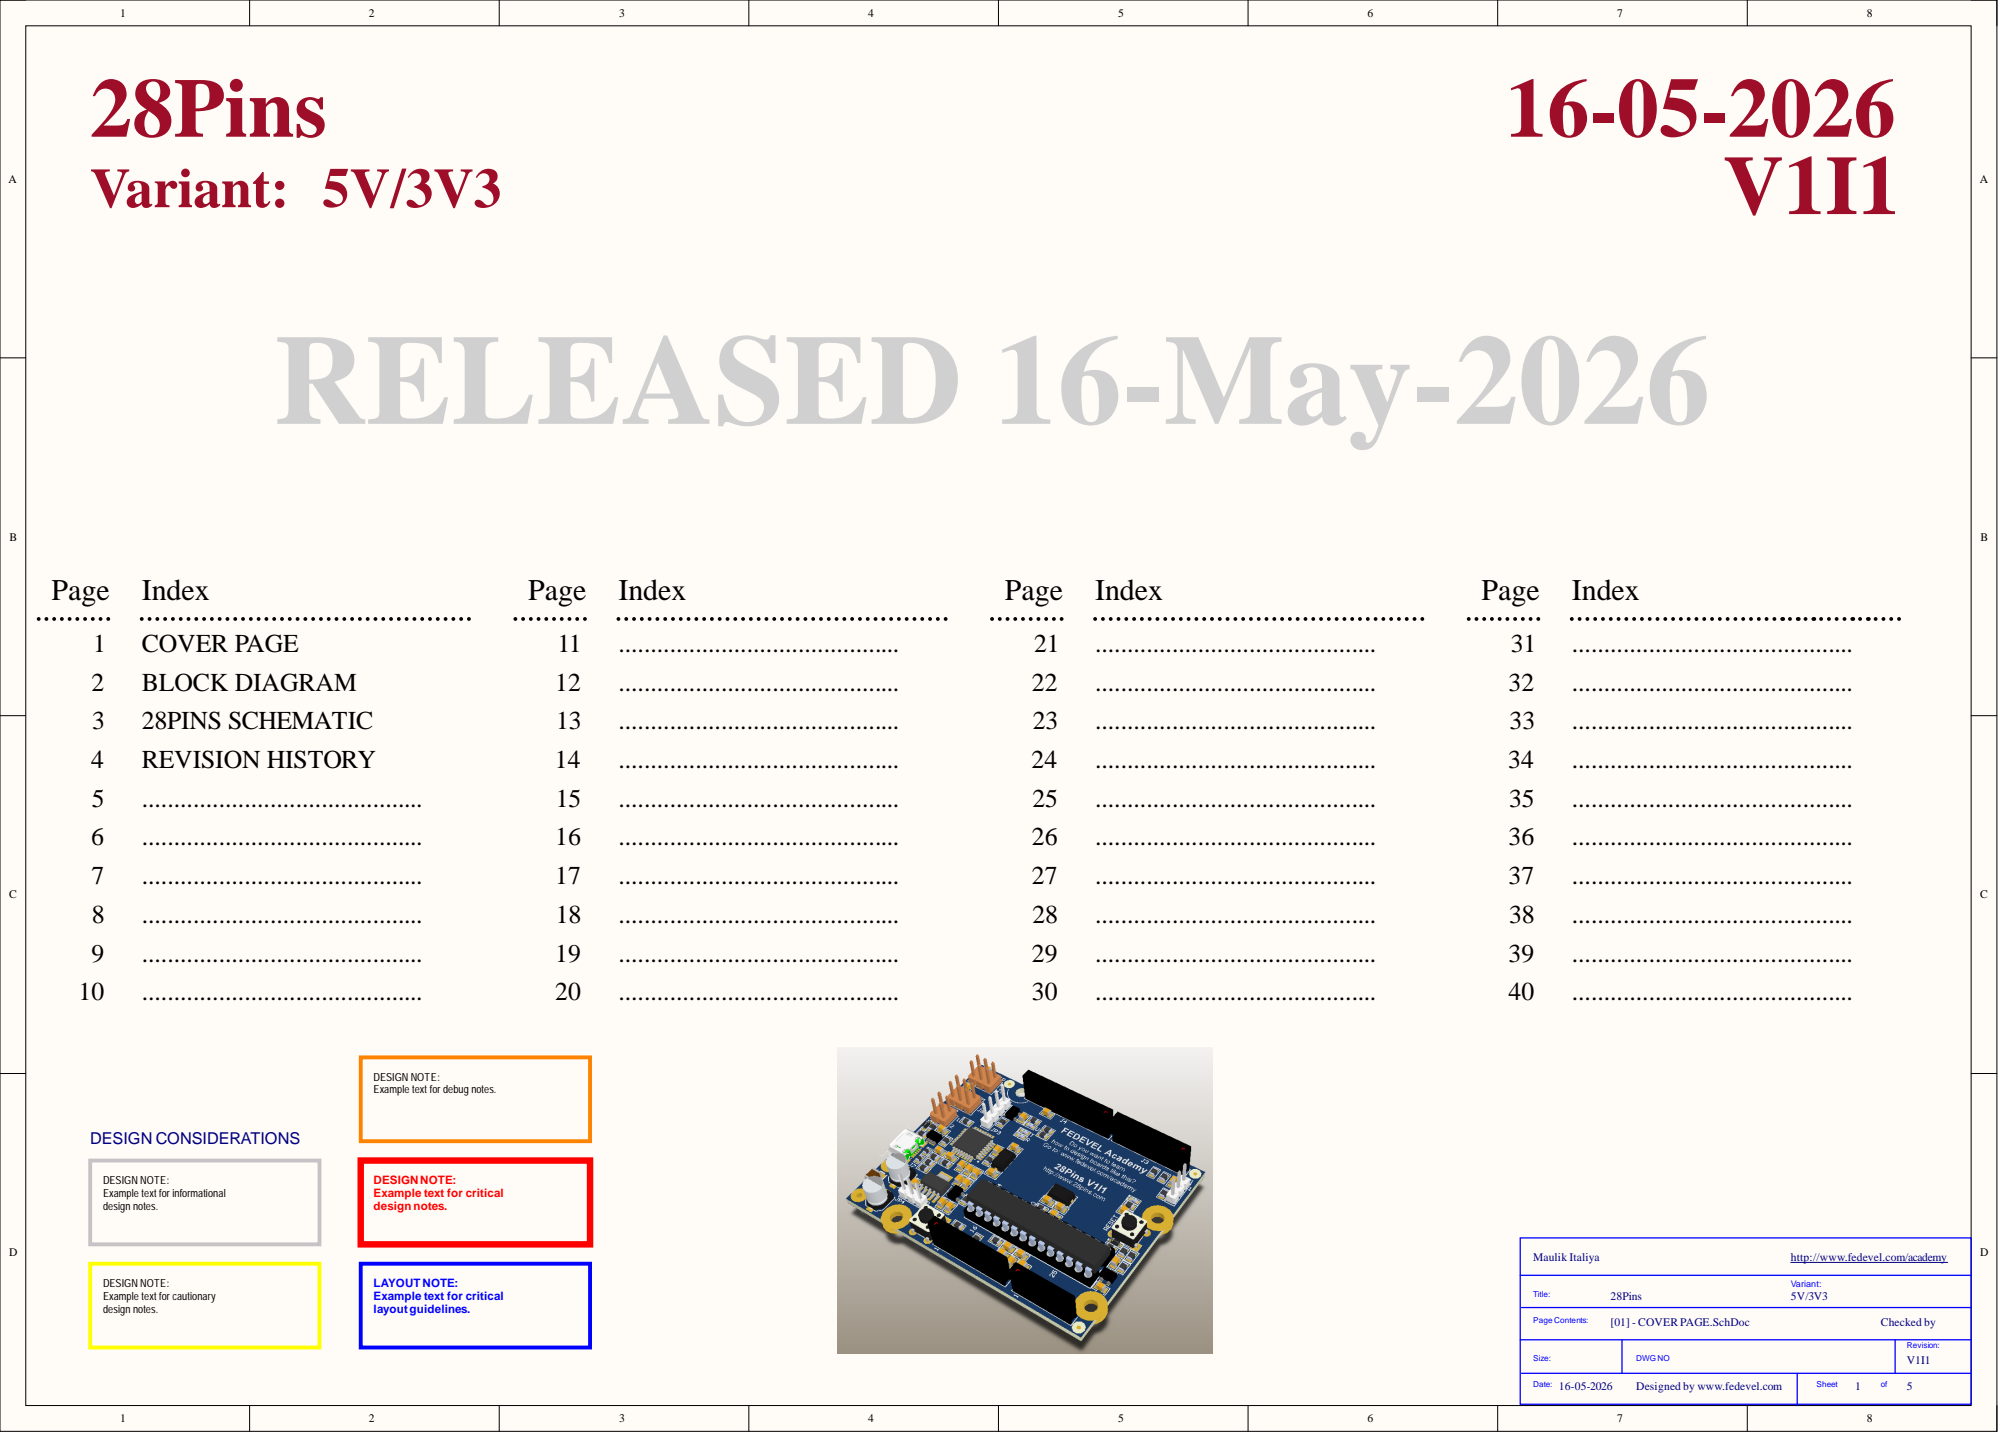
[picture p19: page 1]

DESIGN NOTE:
Example text for debug notes.

Example text for informational
design notes.

Example text for critical

http://www.fedevel.com/academy

Example text for cautionary

LAYOUT NOTE:
layout guidelines.

Size: | DWG NO | Revision: V1I1

Date: 16-05-2026 Designed by www.fedevel.com | Sheet of

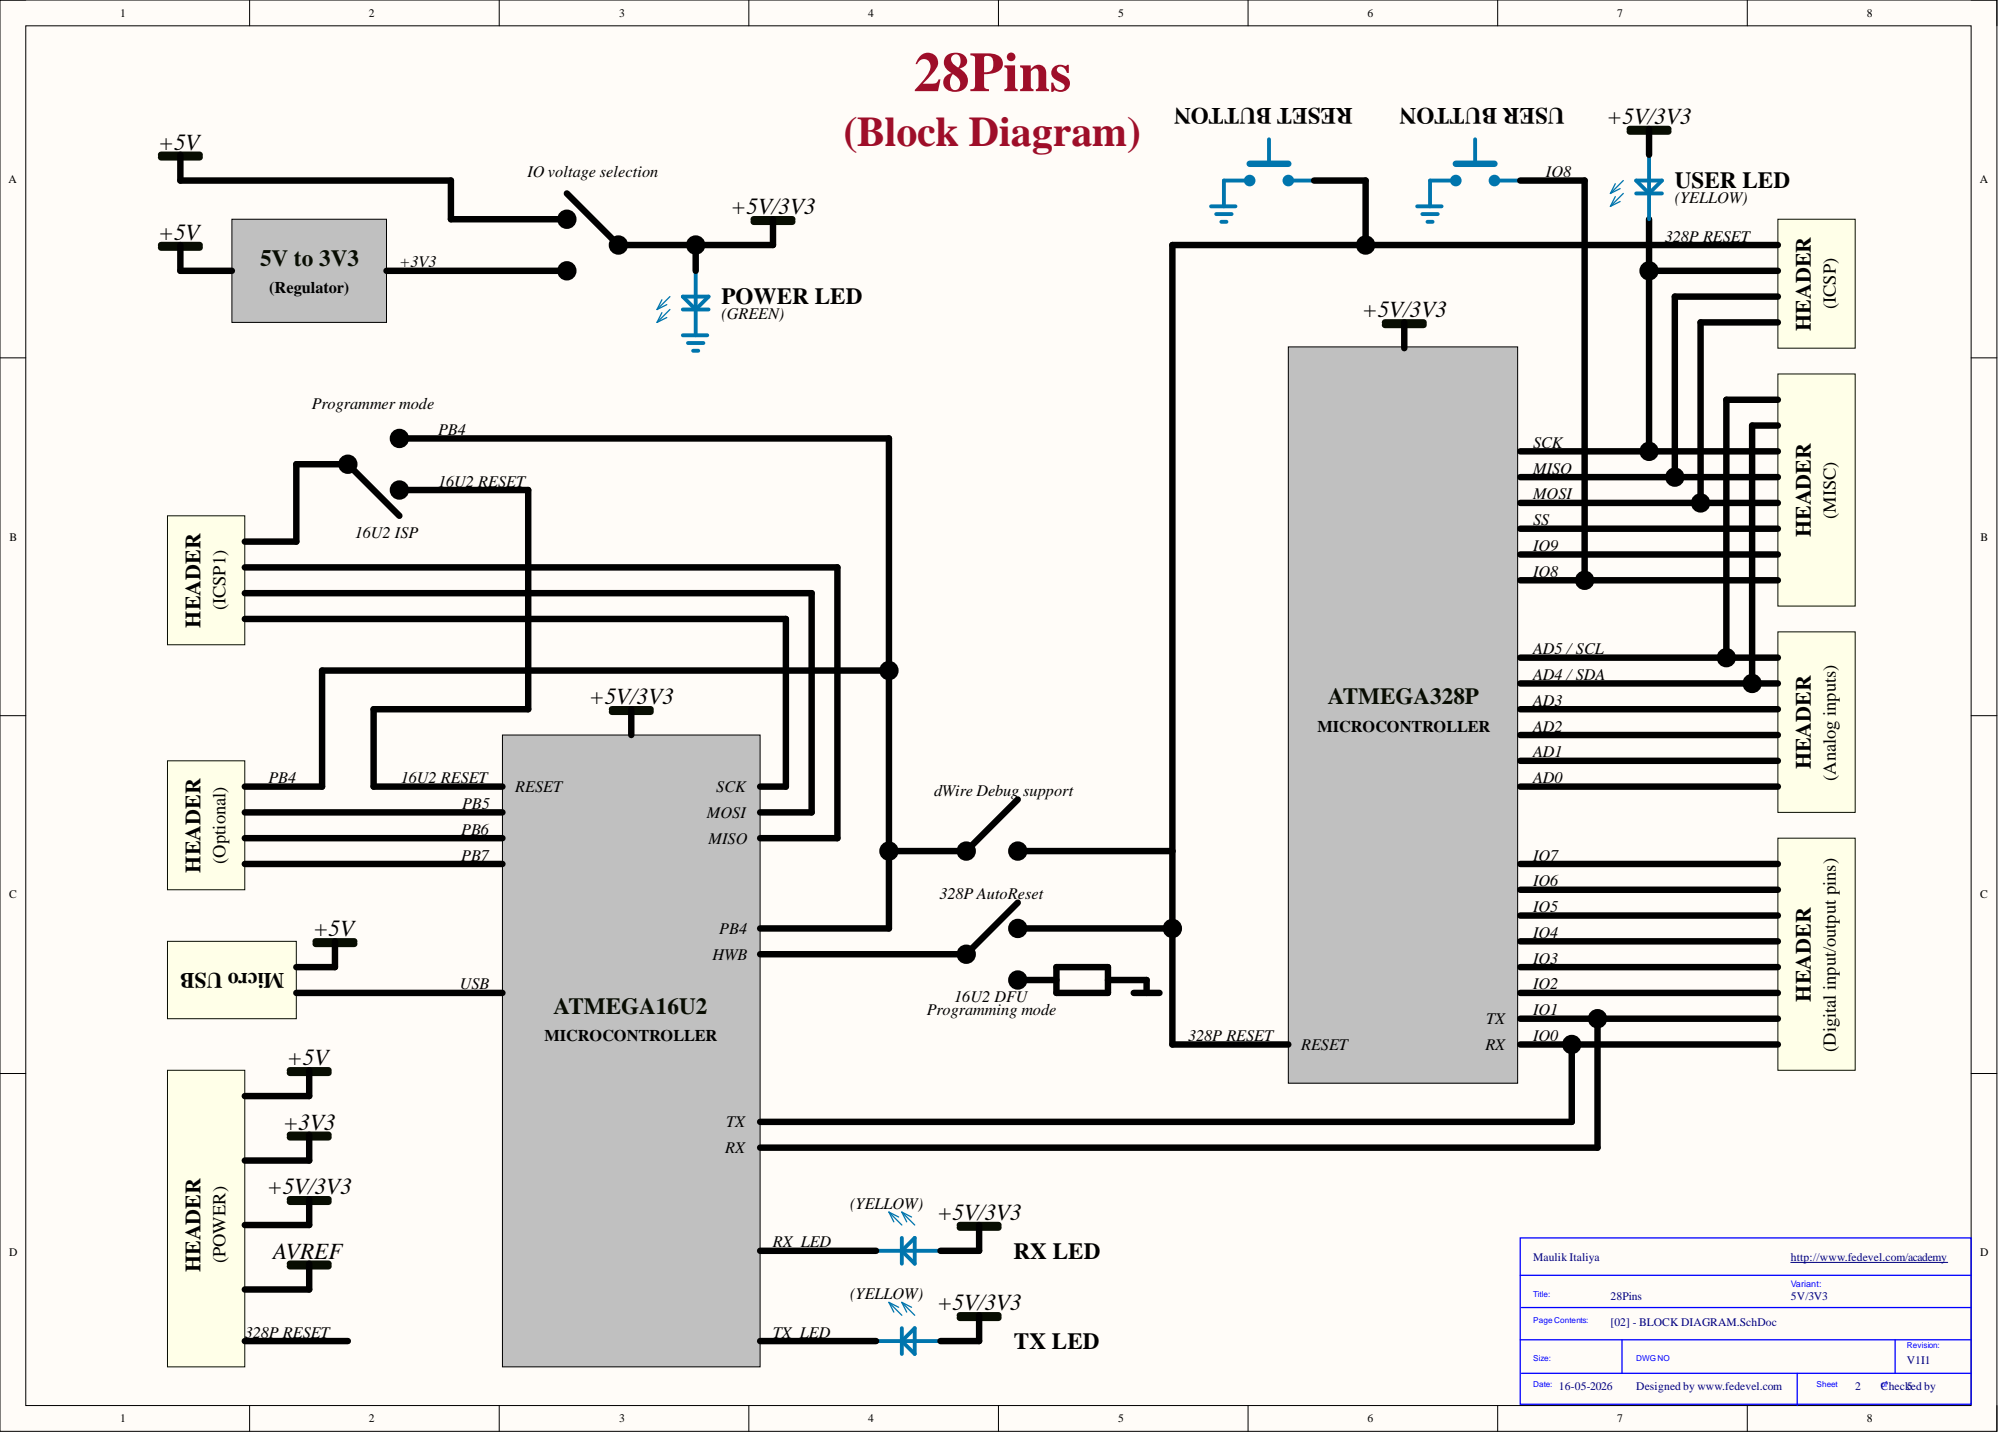
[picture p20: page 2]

MISO
MOSI
SS
IO9
IO8

AD5 / SCL
AD4 / SDA

http://www.fedevel.com/academy

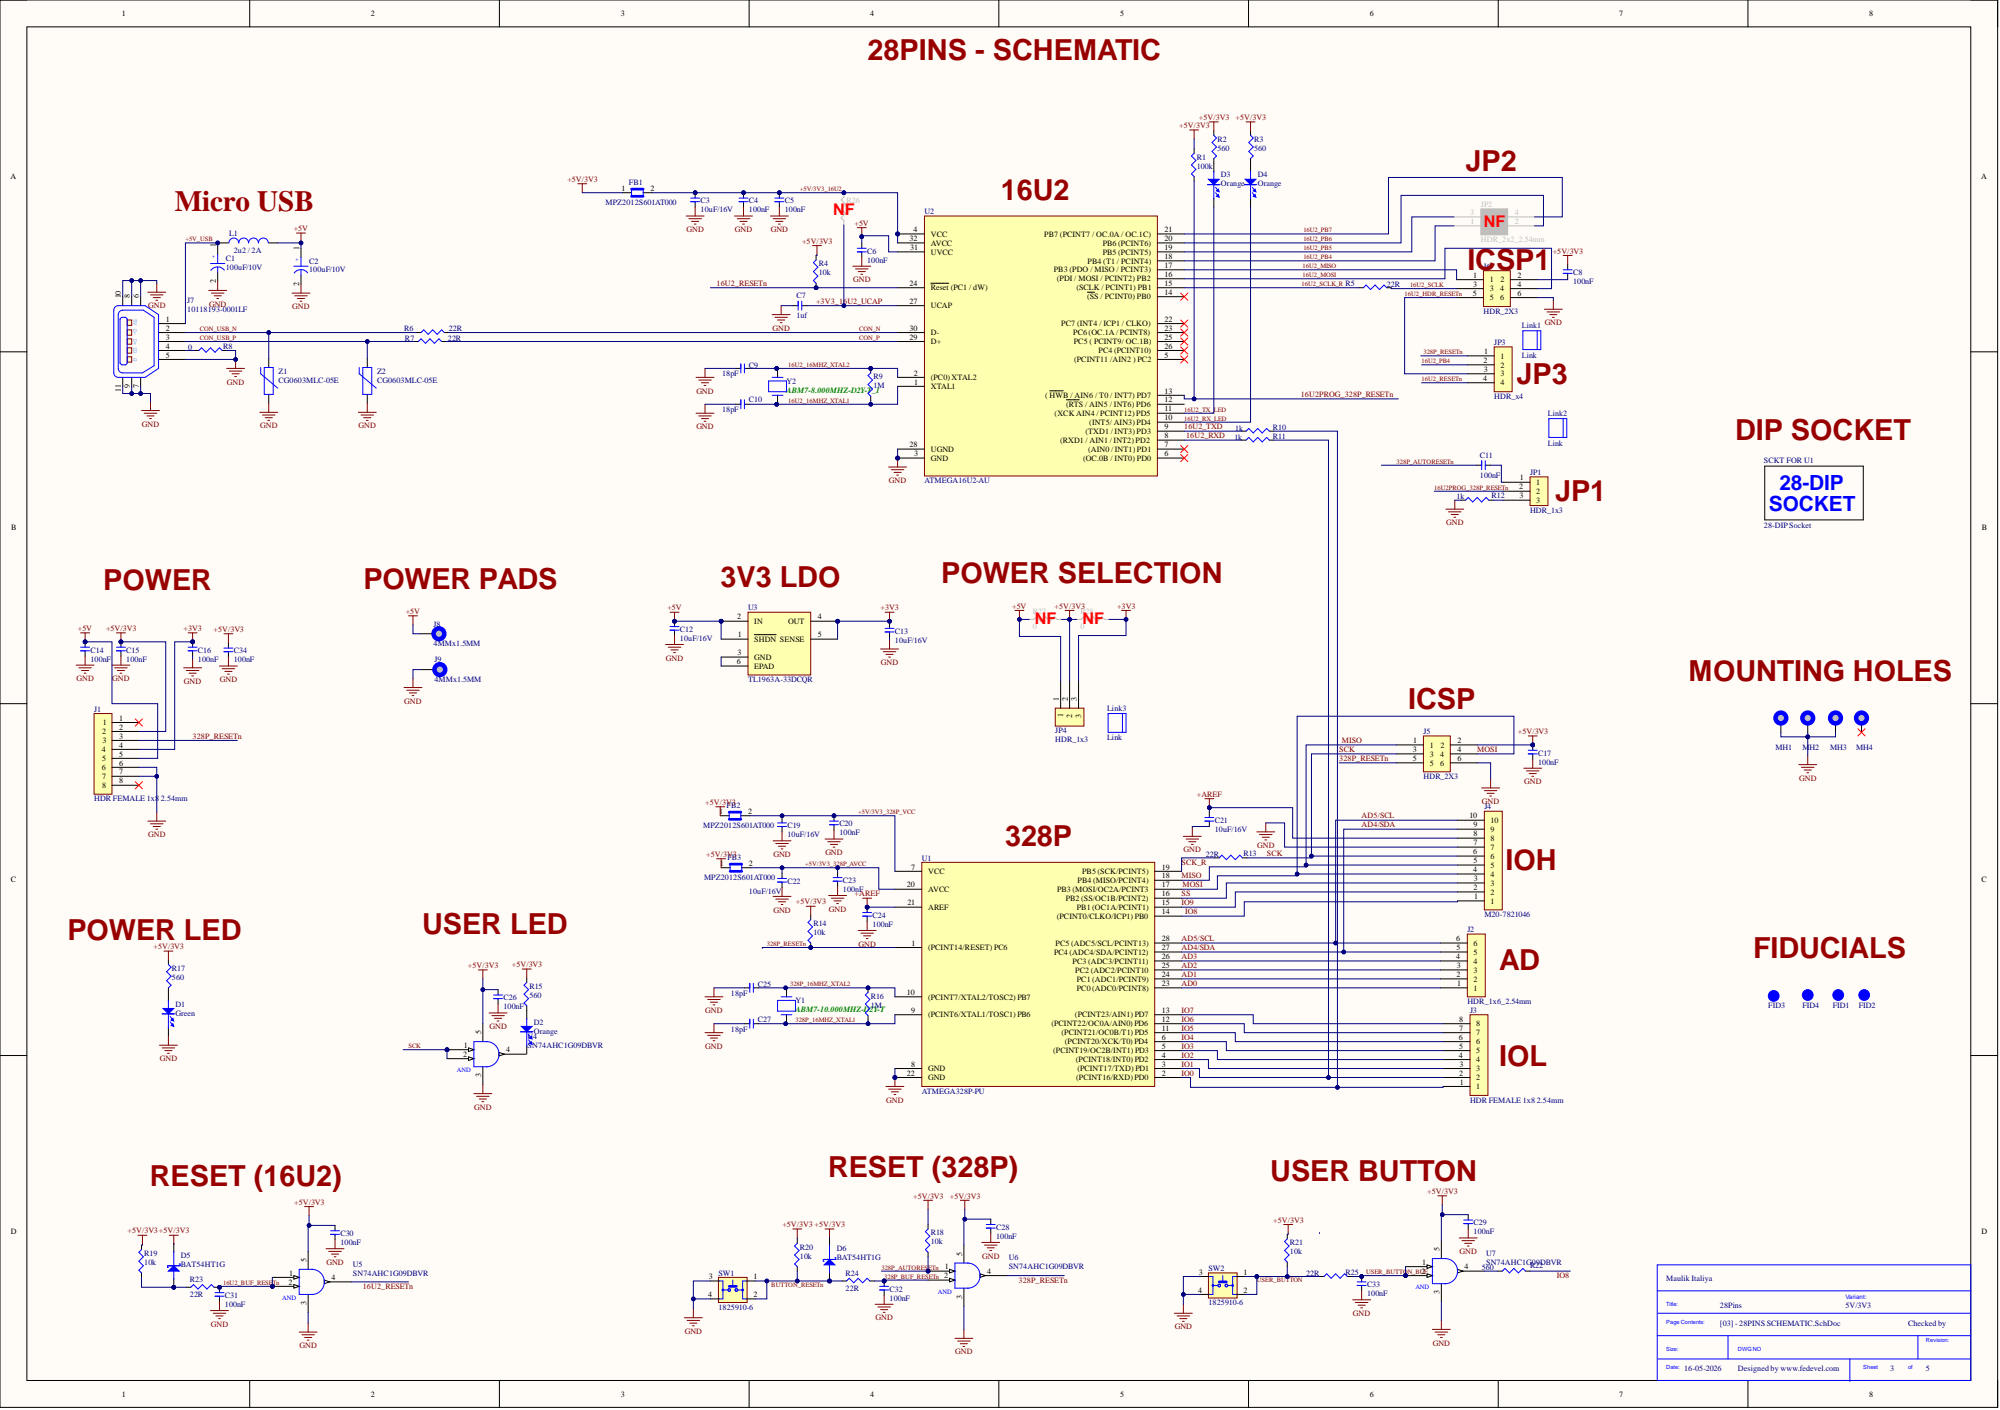
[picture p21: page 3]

ICSP1 J6

16U2_PB4
16U2_MISO

SCK | MOSI
328P_RESETn

C21 10uF/16V | | AD5/SCL

AD4/SDA

AREF 21 | | SS

(PCINT14/RESET) PC6 1 | | IO8

AD5/SCL

AD2
AD1
AD0
IO4 | 1 1 2 2 3 3 4 4 5 5 6 6 7 7 8 8
IO5

Y1 1M ABM7-10.000MHZ-D2Y-T | (PCINT6/XTAL1/TOSC1) PB6 9

IO2
IO1

GND 22 | IO0

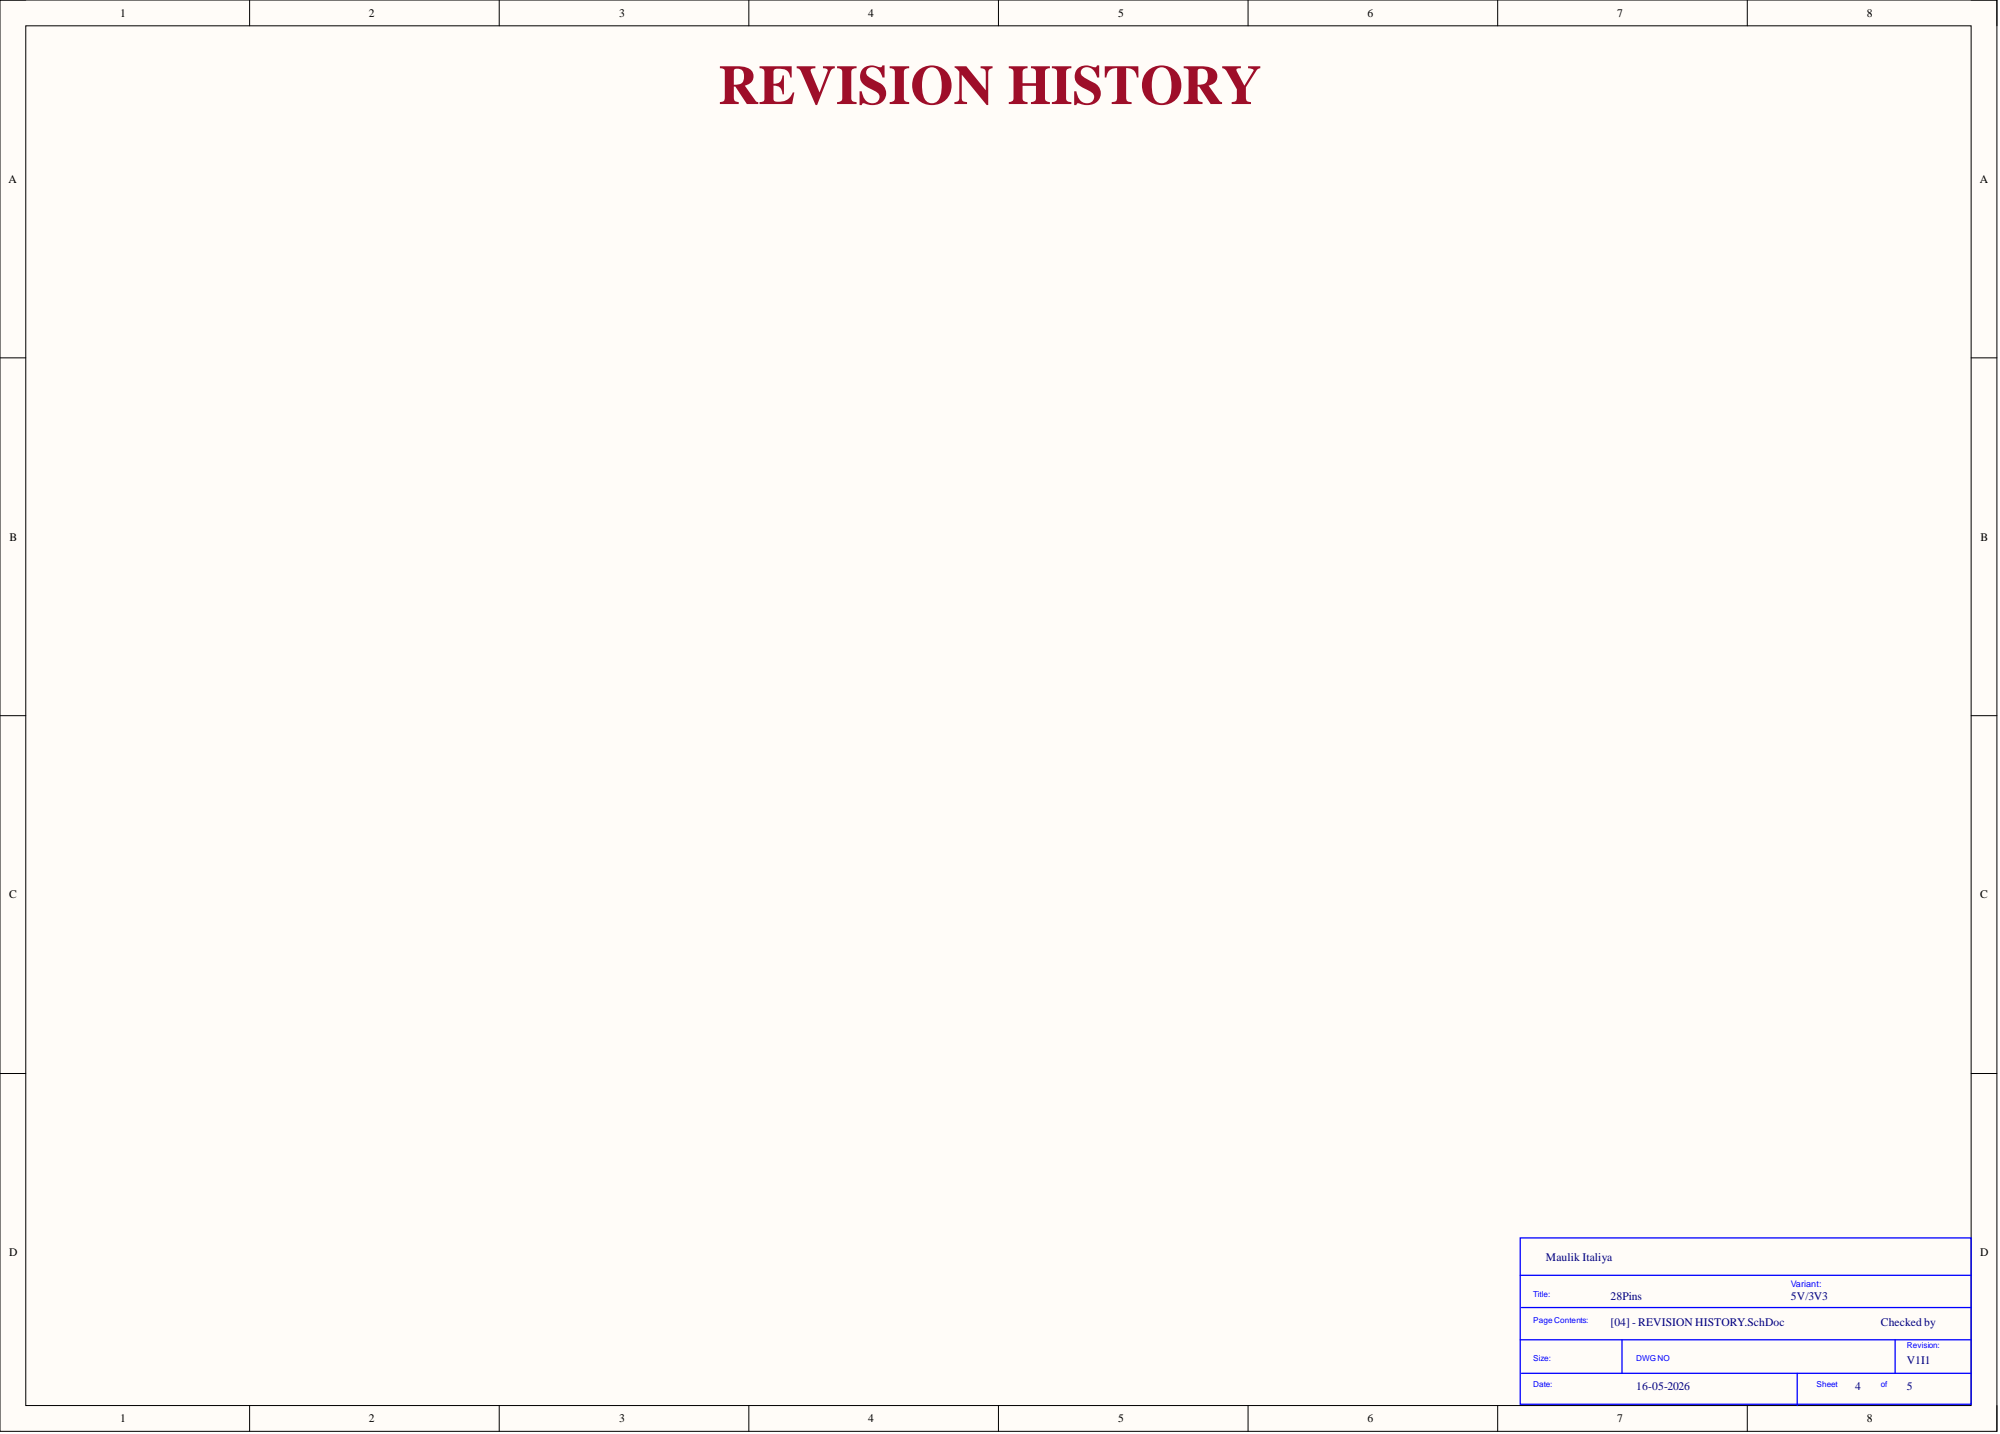
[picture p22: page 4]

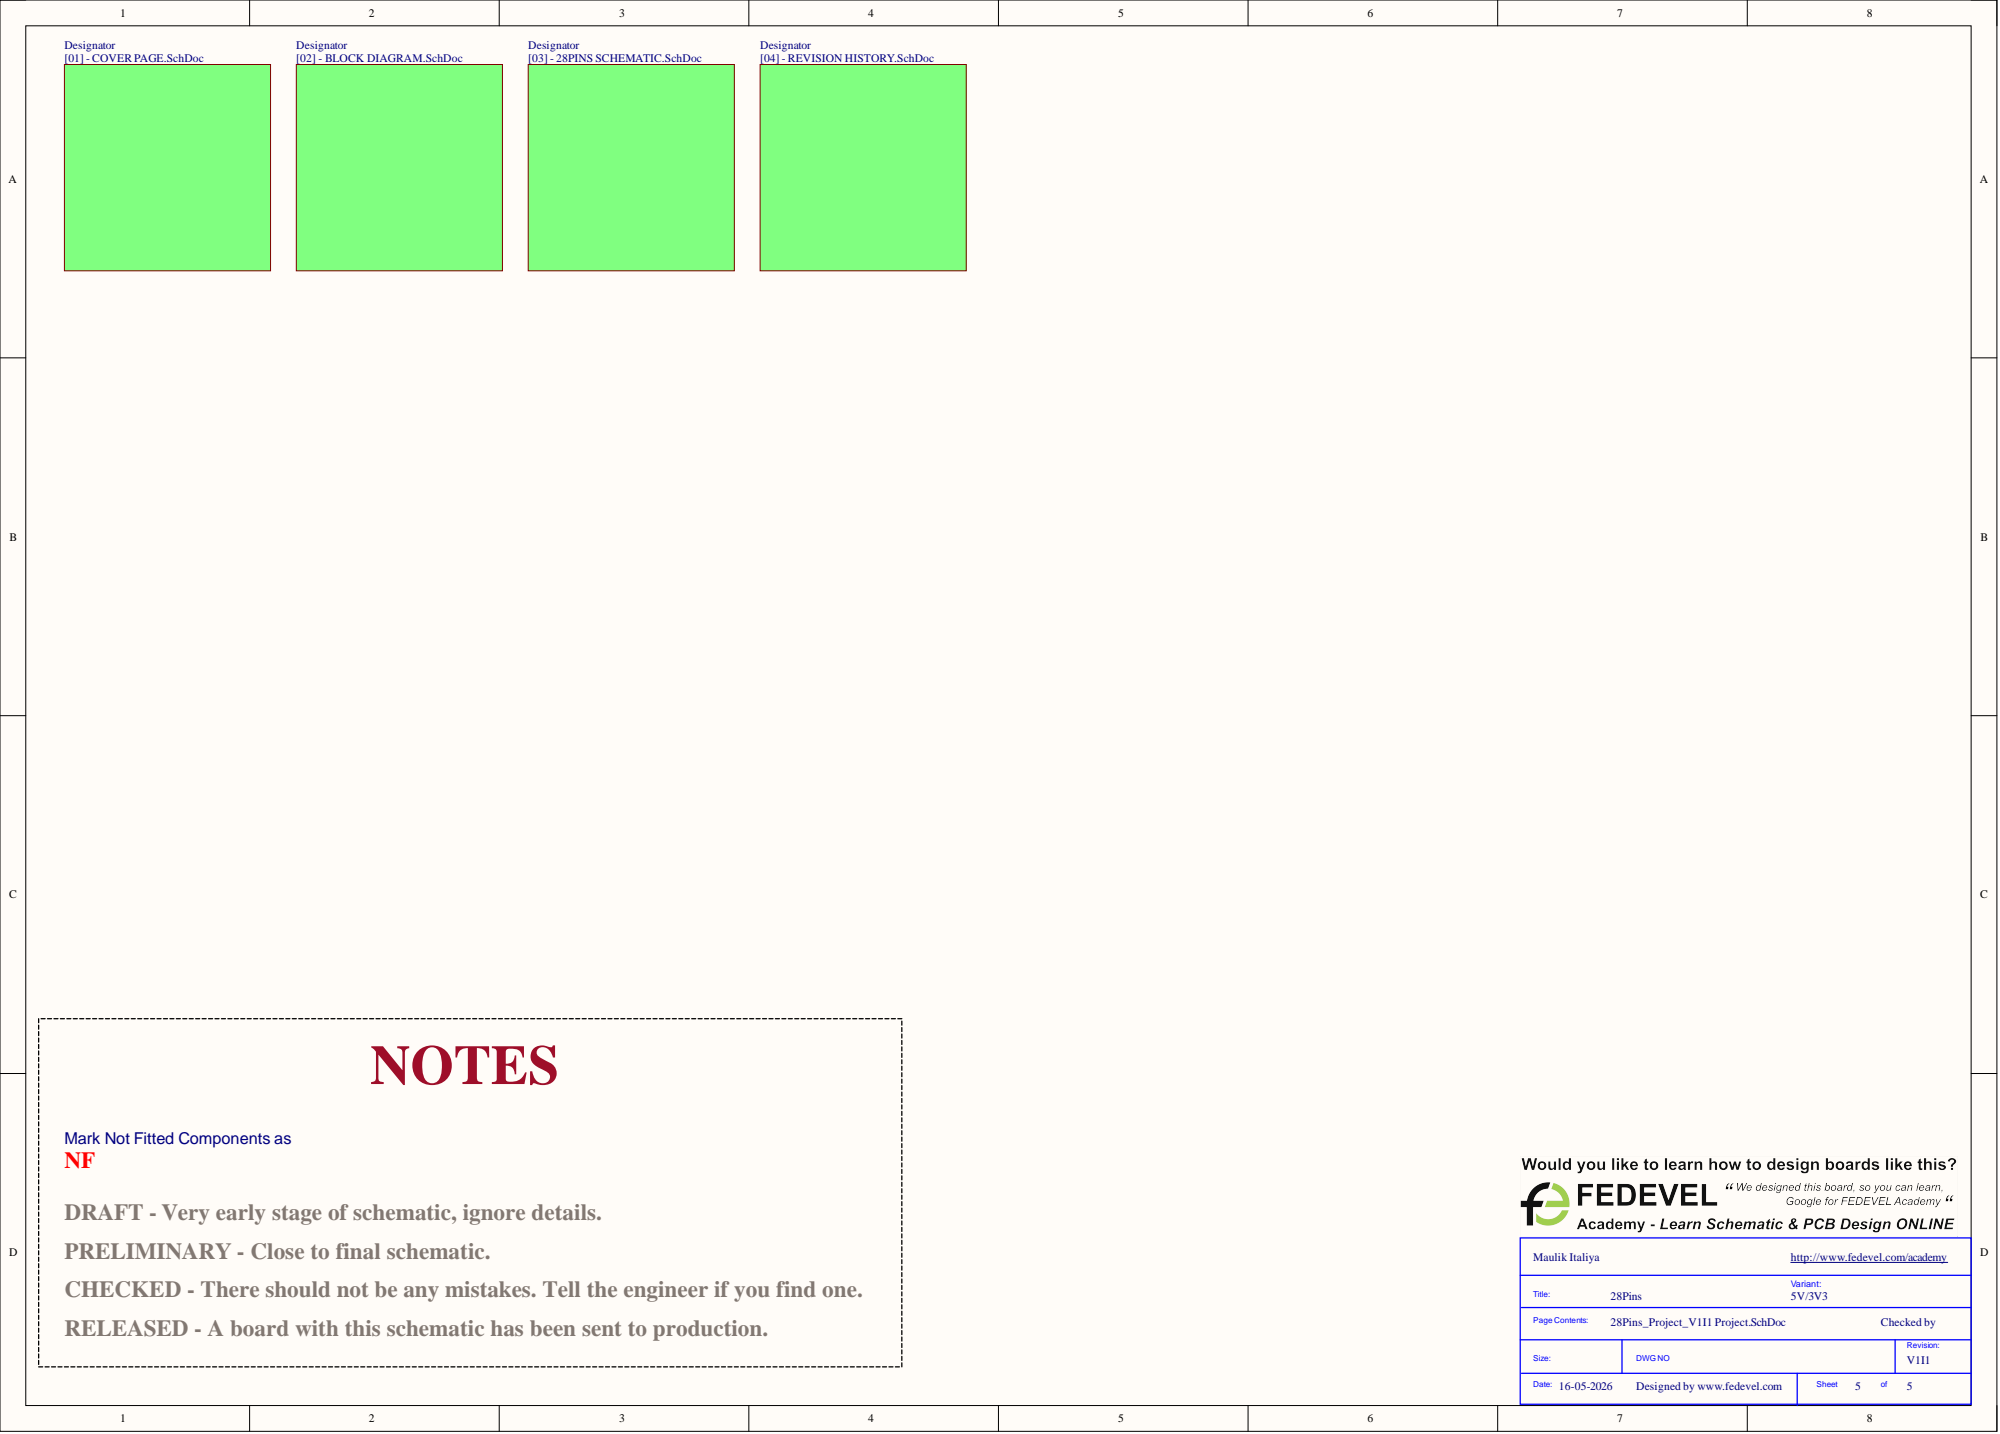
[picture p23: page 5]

Mark Not Fitted Components as

DRAFT - Very early stage of schematic, ignore details.
PRELIMINARY - Close to final schematic.
CHECKED - There should not be any mistakes. Tell the engineer if you find one.
RELEASED - A board with this schematic has been sent to production.

http://www.fedevel.com/academy

Designed by www.fedevel.com

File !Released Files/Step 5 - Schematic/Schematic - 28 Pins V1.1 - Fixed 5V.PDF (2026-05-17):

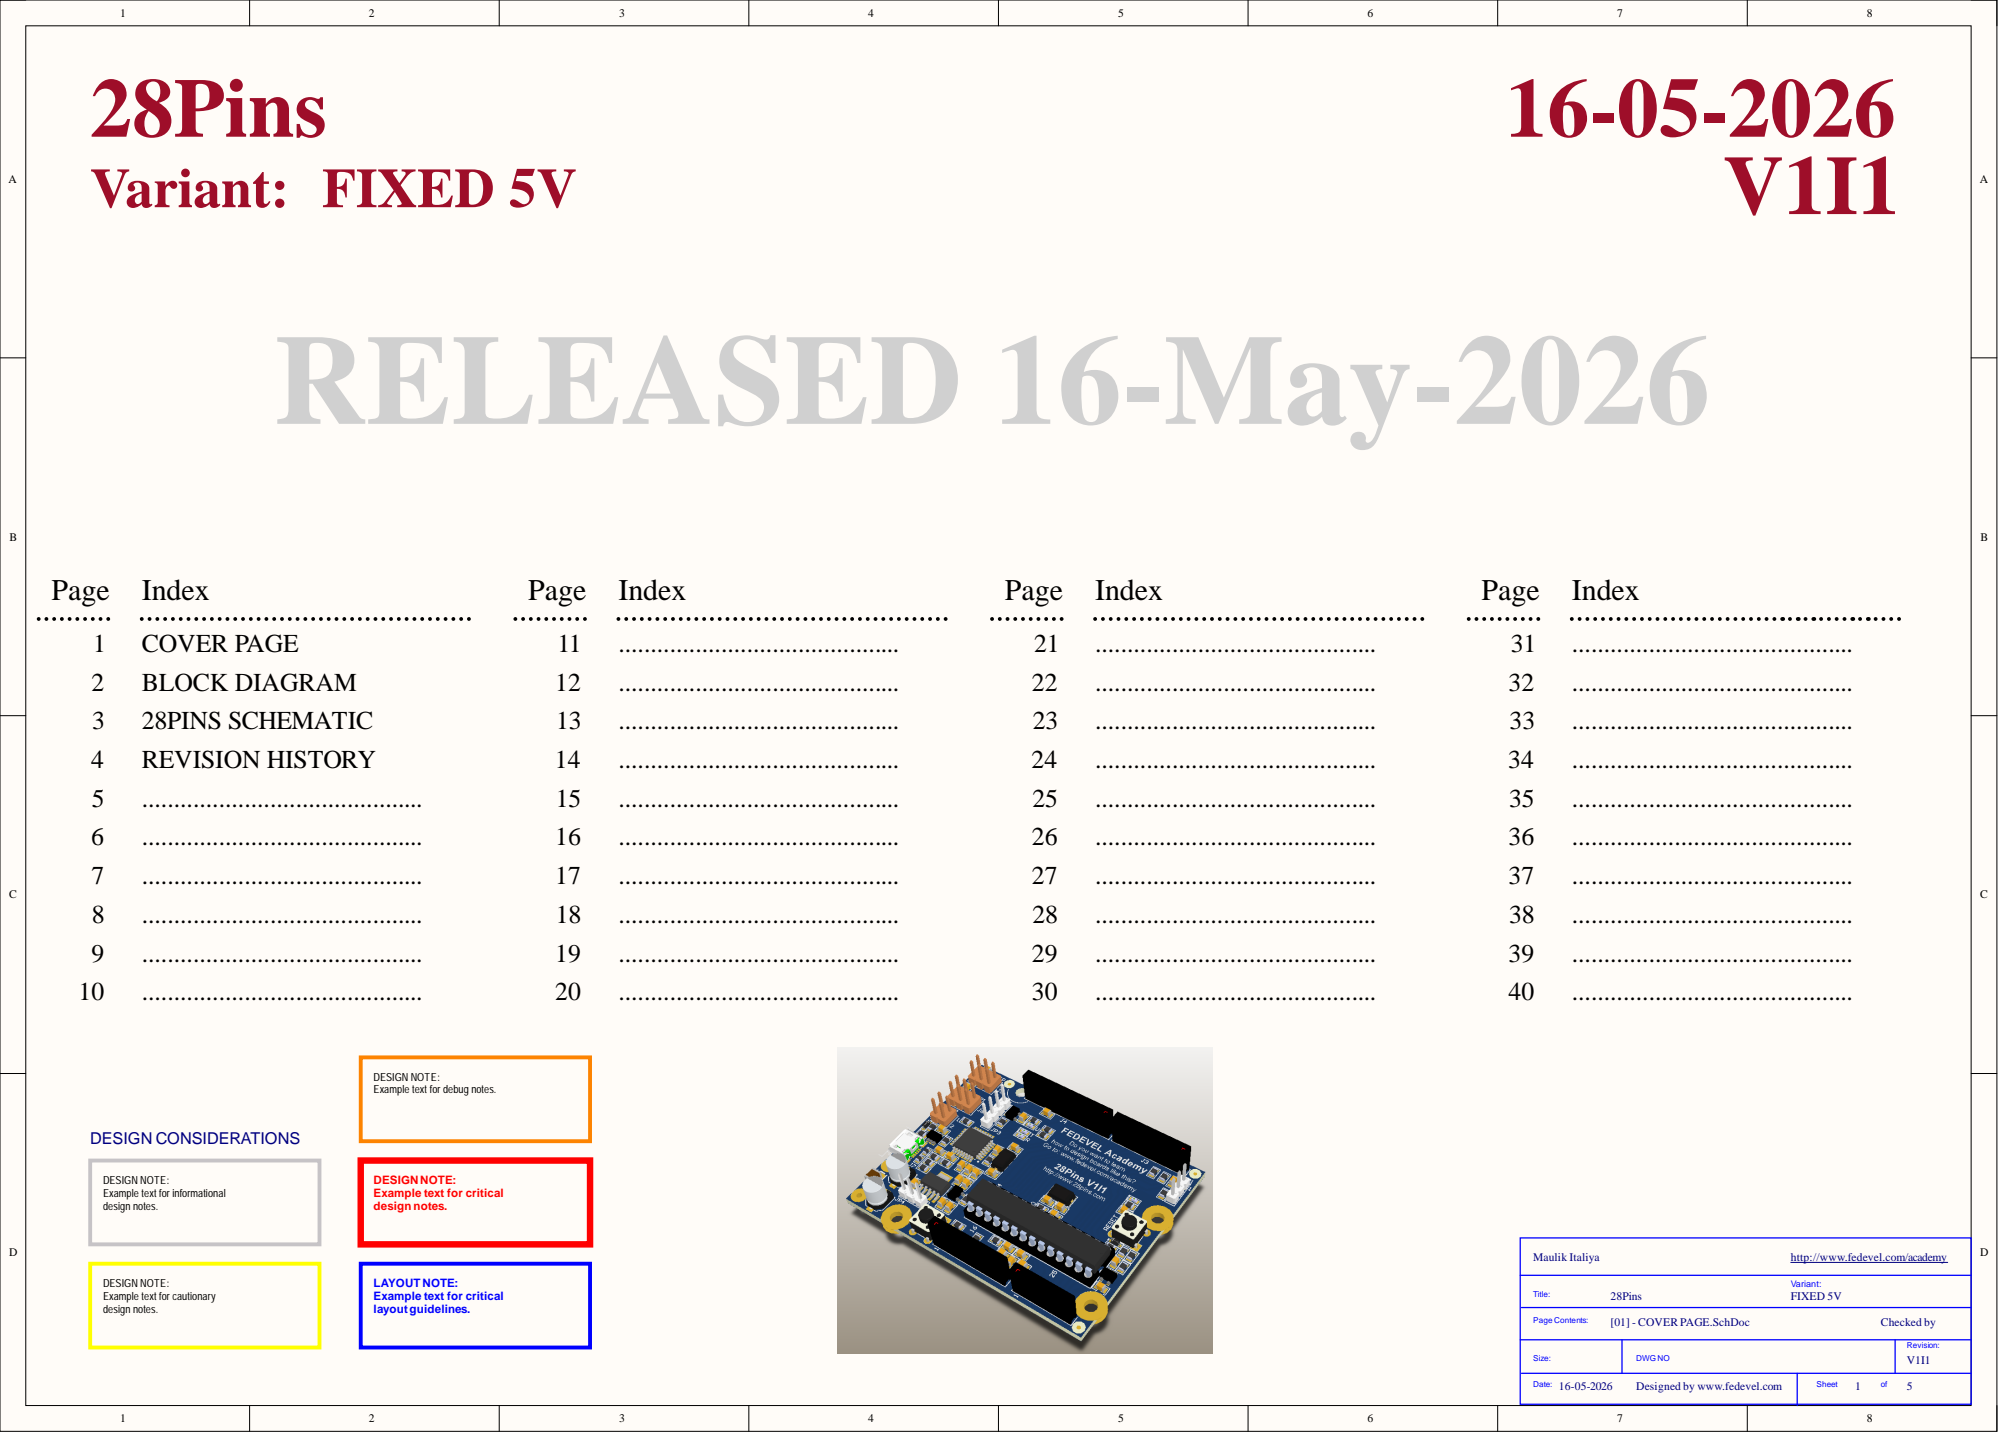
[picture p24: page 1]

DESIGN NOTE:
Example text for debug notes.

Example text for informational
design notes.

Example text for critical

http://www.fedevel.com/academy

Example text for cautionary

LAYOUT NOTE:
layout guidelines.

Size: | DWG NO | Revision: V1I1

Date: 16-05-2026 Designed by www.fedevel.com | Sheet of

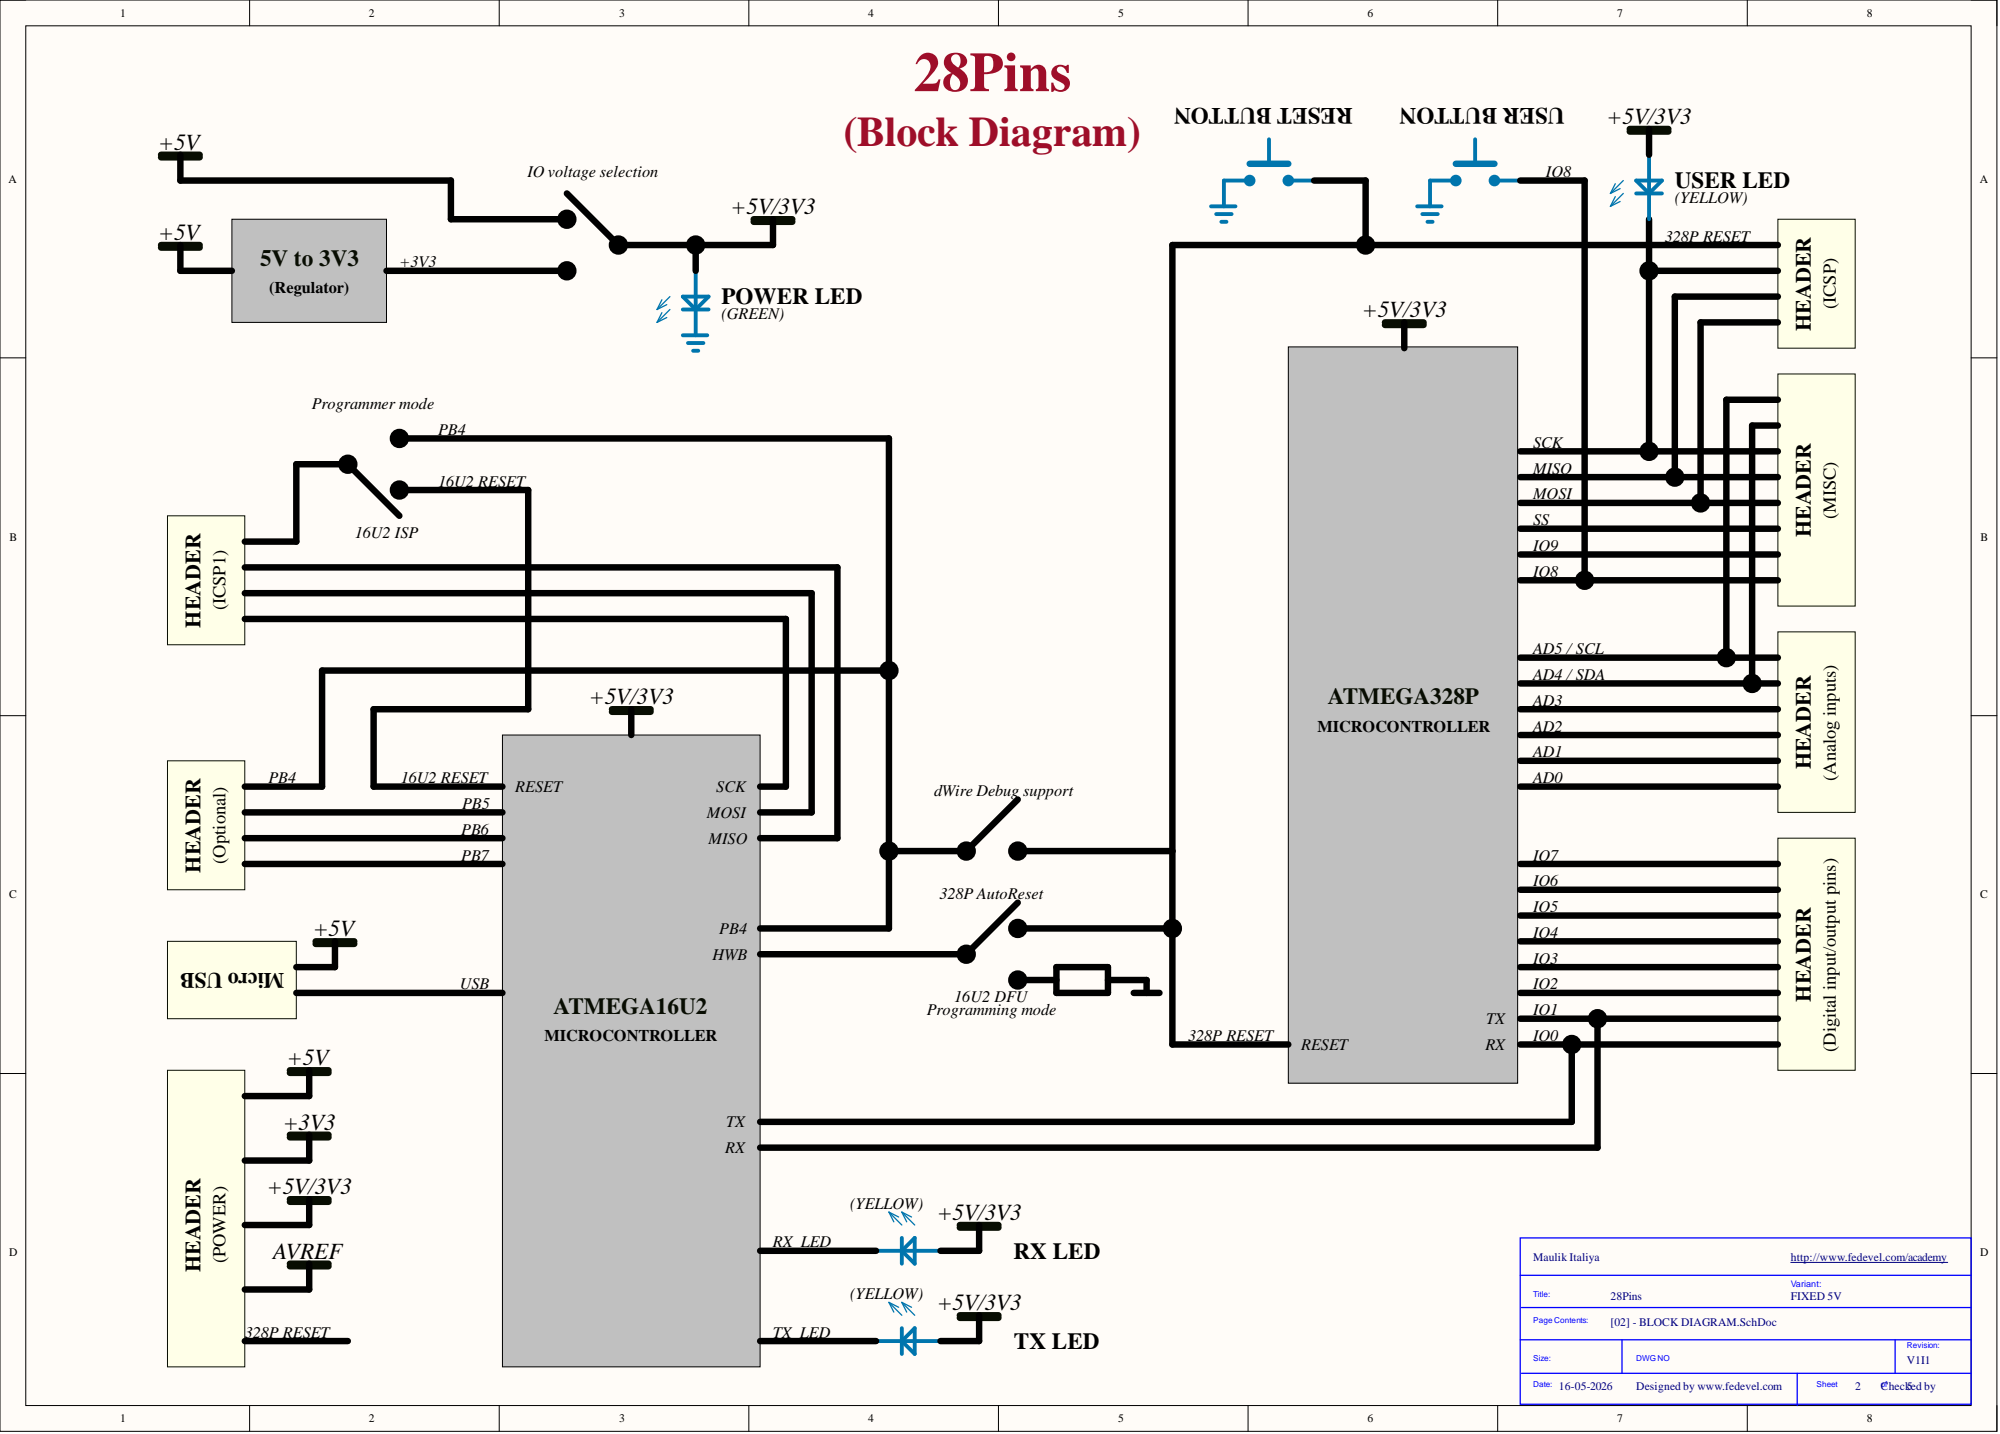
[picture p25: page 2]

MISO
MOSI
SS
IO9
IO8

AD5 / SCL
AD4 / SDA

http://www.fedevel.com/academy

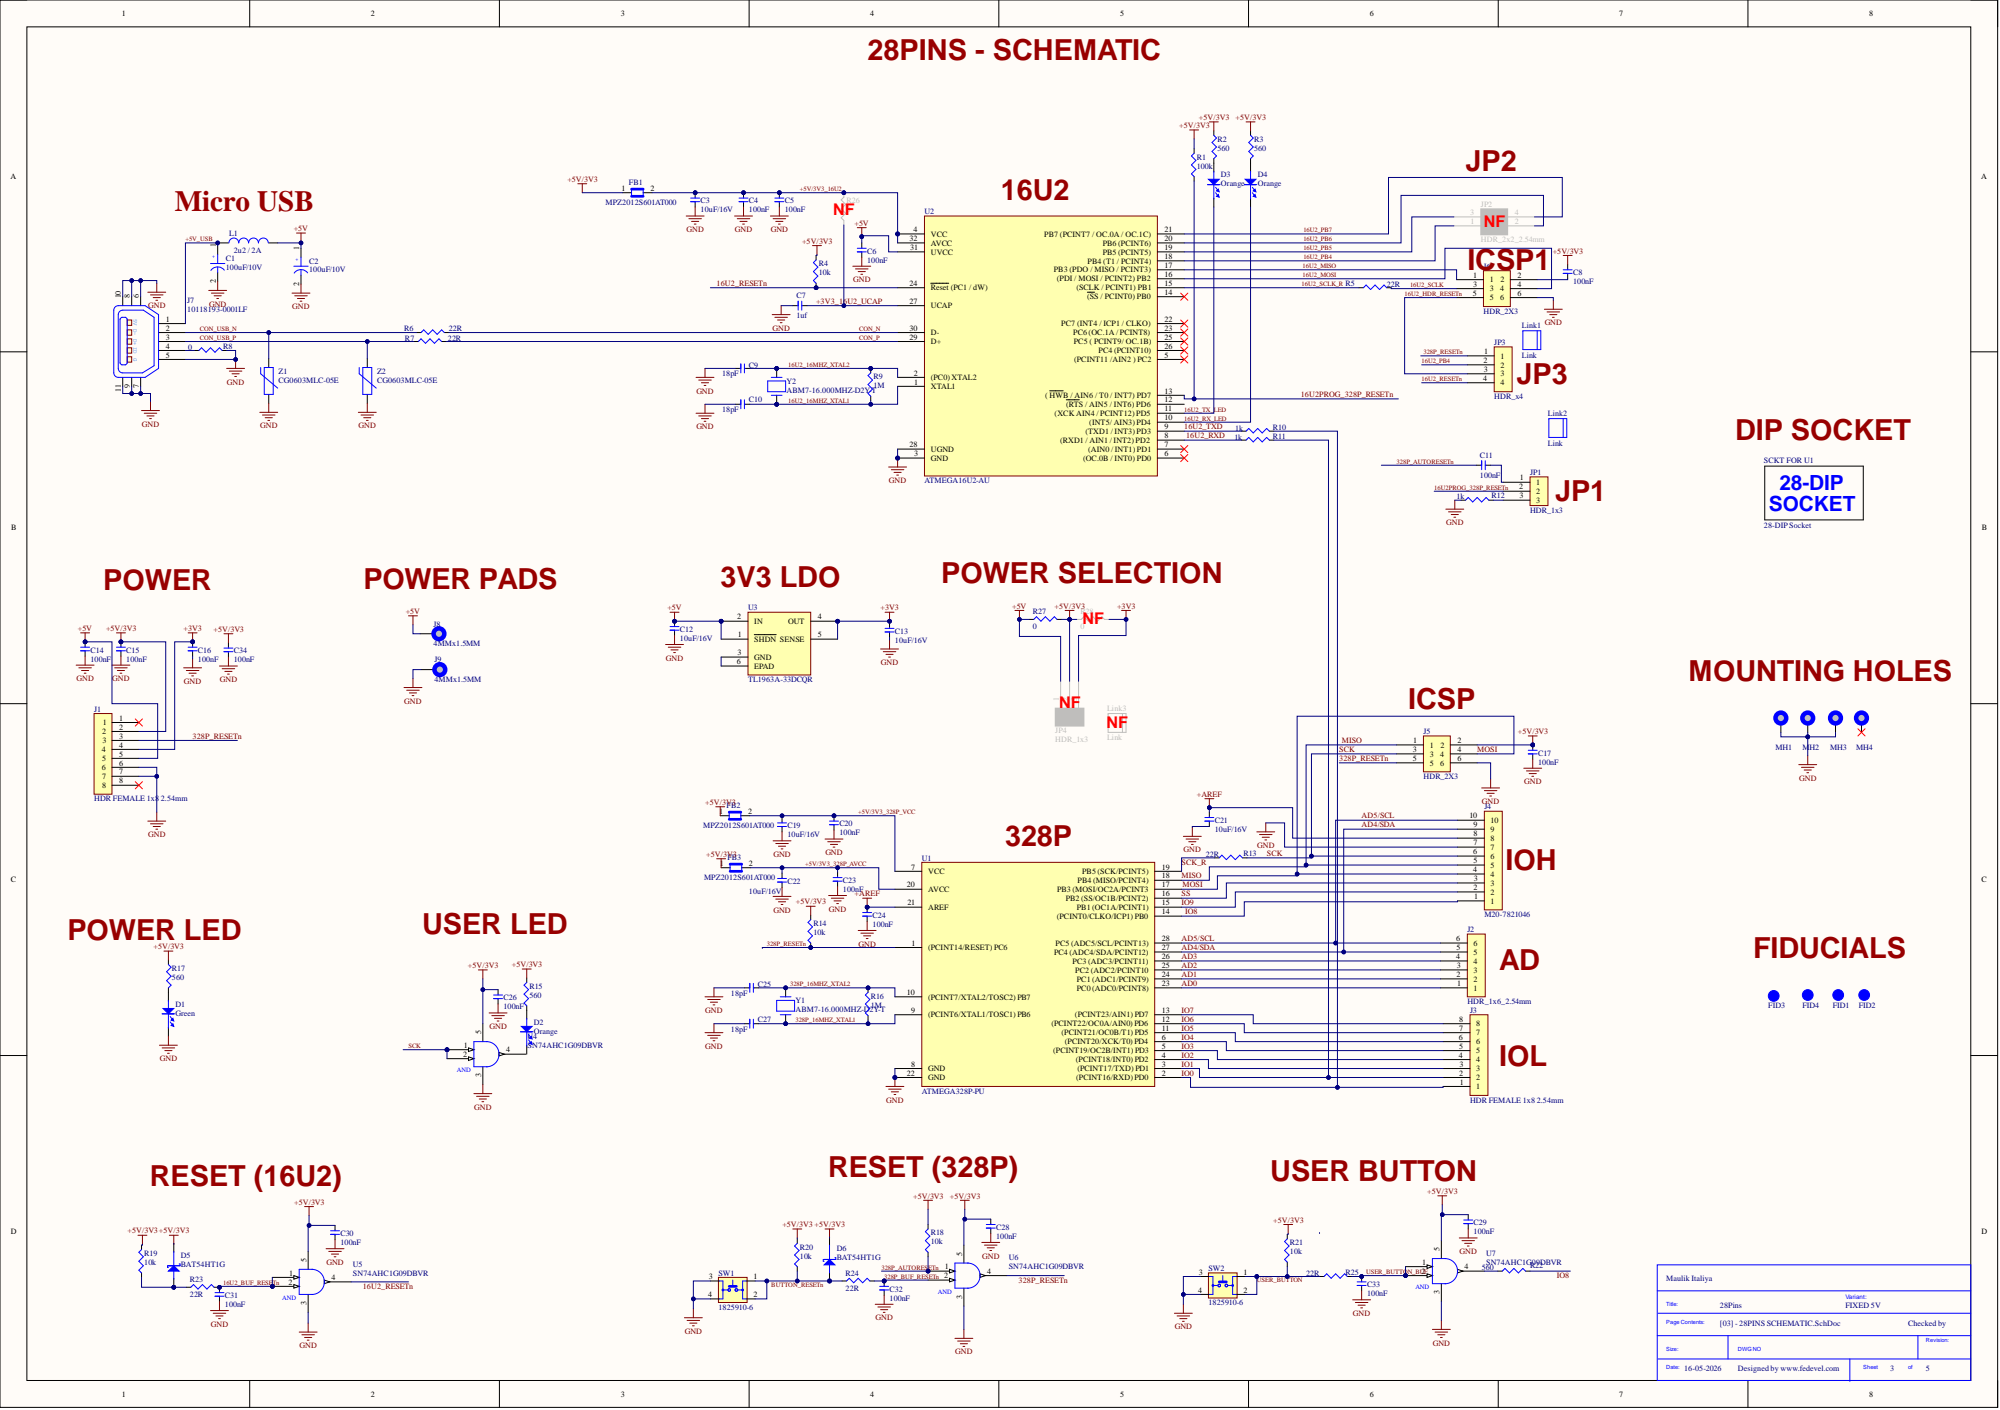
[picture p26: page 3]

ICSP1 J6

16U2_PB4
16U2_MISO

16U2_16MHZ_XTAL1 | | UGND 28

SCK | MOSI
328P_RESETn

C21 10uF/16V | | AD5/SCL

AD4/SDA

AREF 21 | | SS

(PCINT14/RESET) PC6 1 | | IO8

AD5/SCL

AD2
AD1
AD0
IO4 | 1 1 2 2 3 3 4 4 5 5 6 6 7 7 8 8
IO5

Y1 1M ABM7-16.000MHZ-D2Y-T | (PCINT6/XTAL1/TOSC1) PB6 9

IO2
IO1

GND 22 | IO0

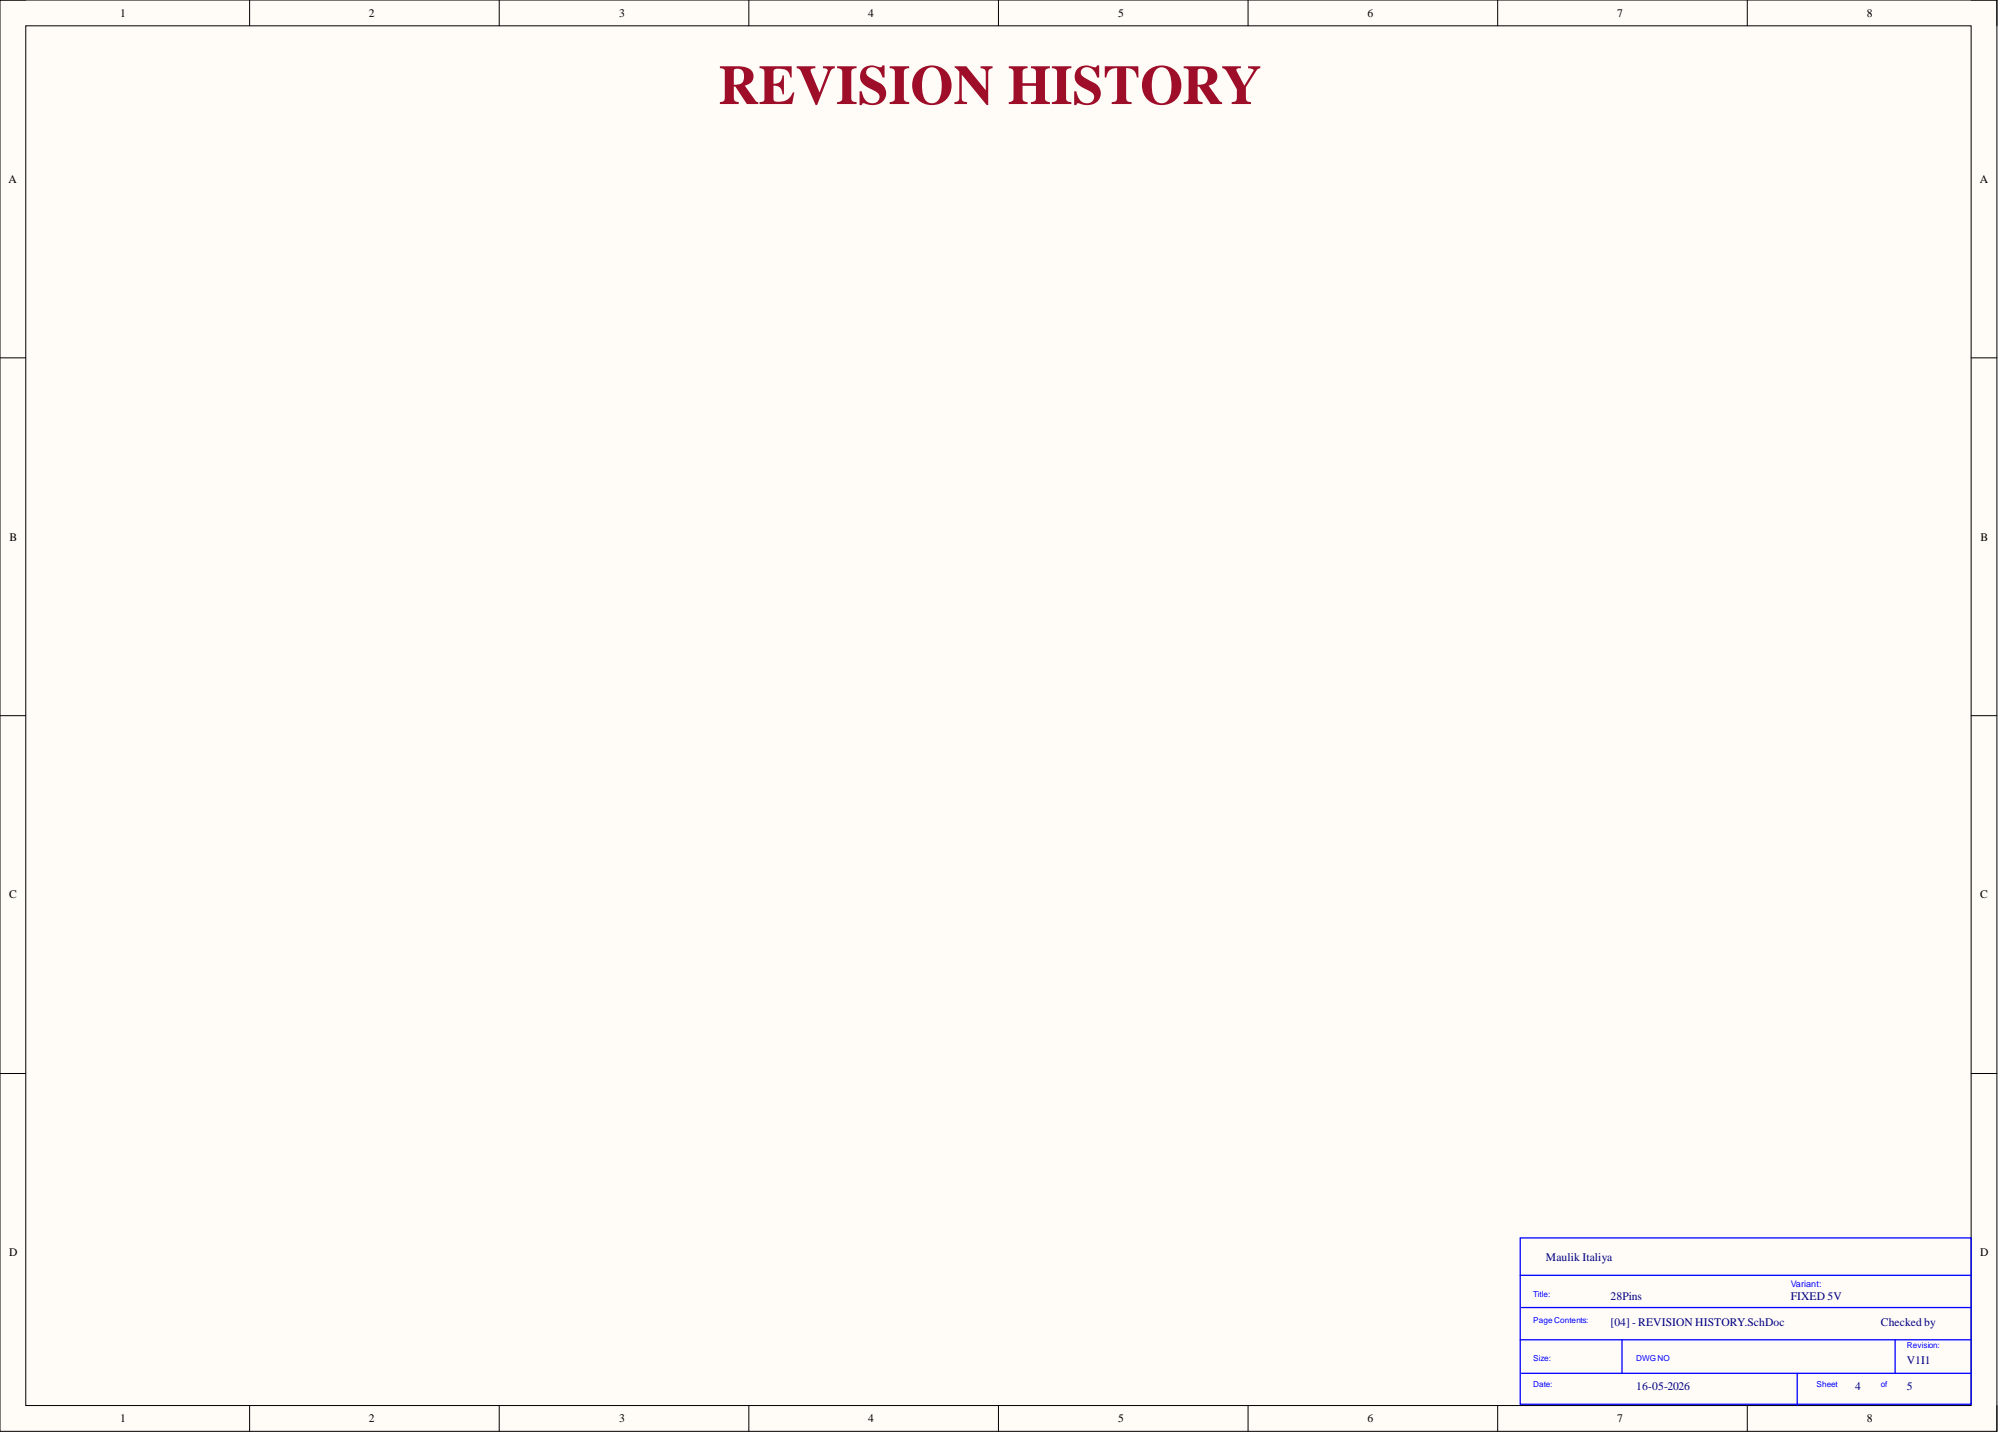
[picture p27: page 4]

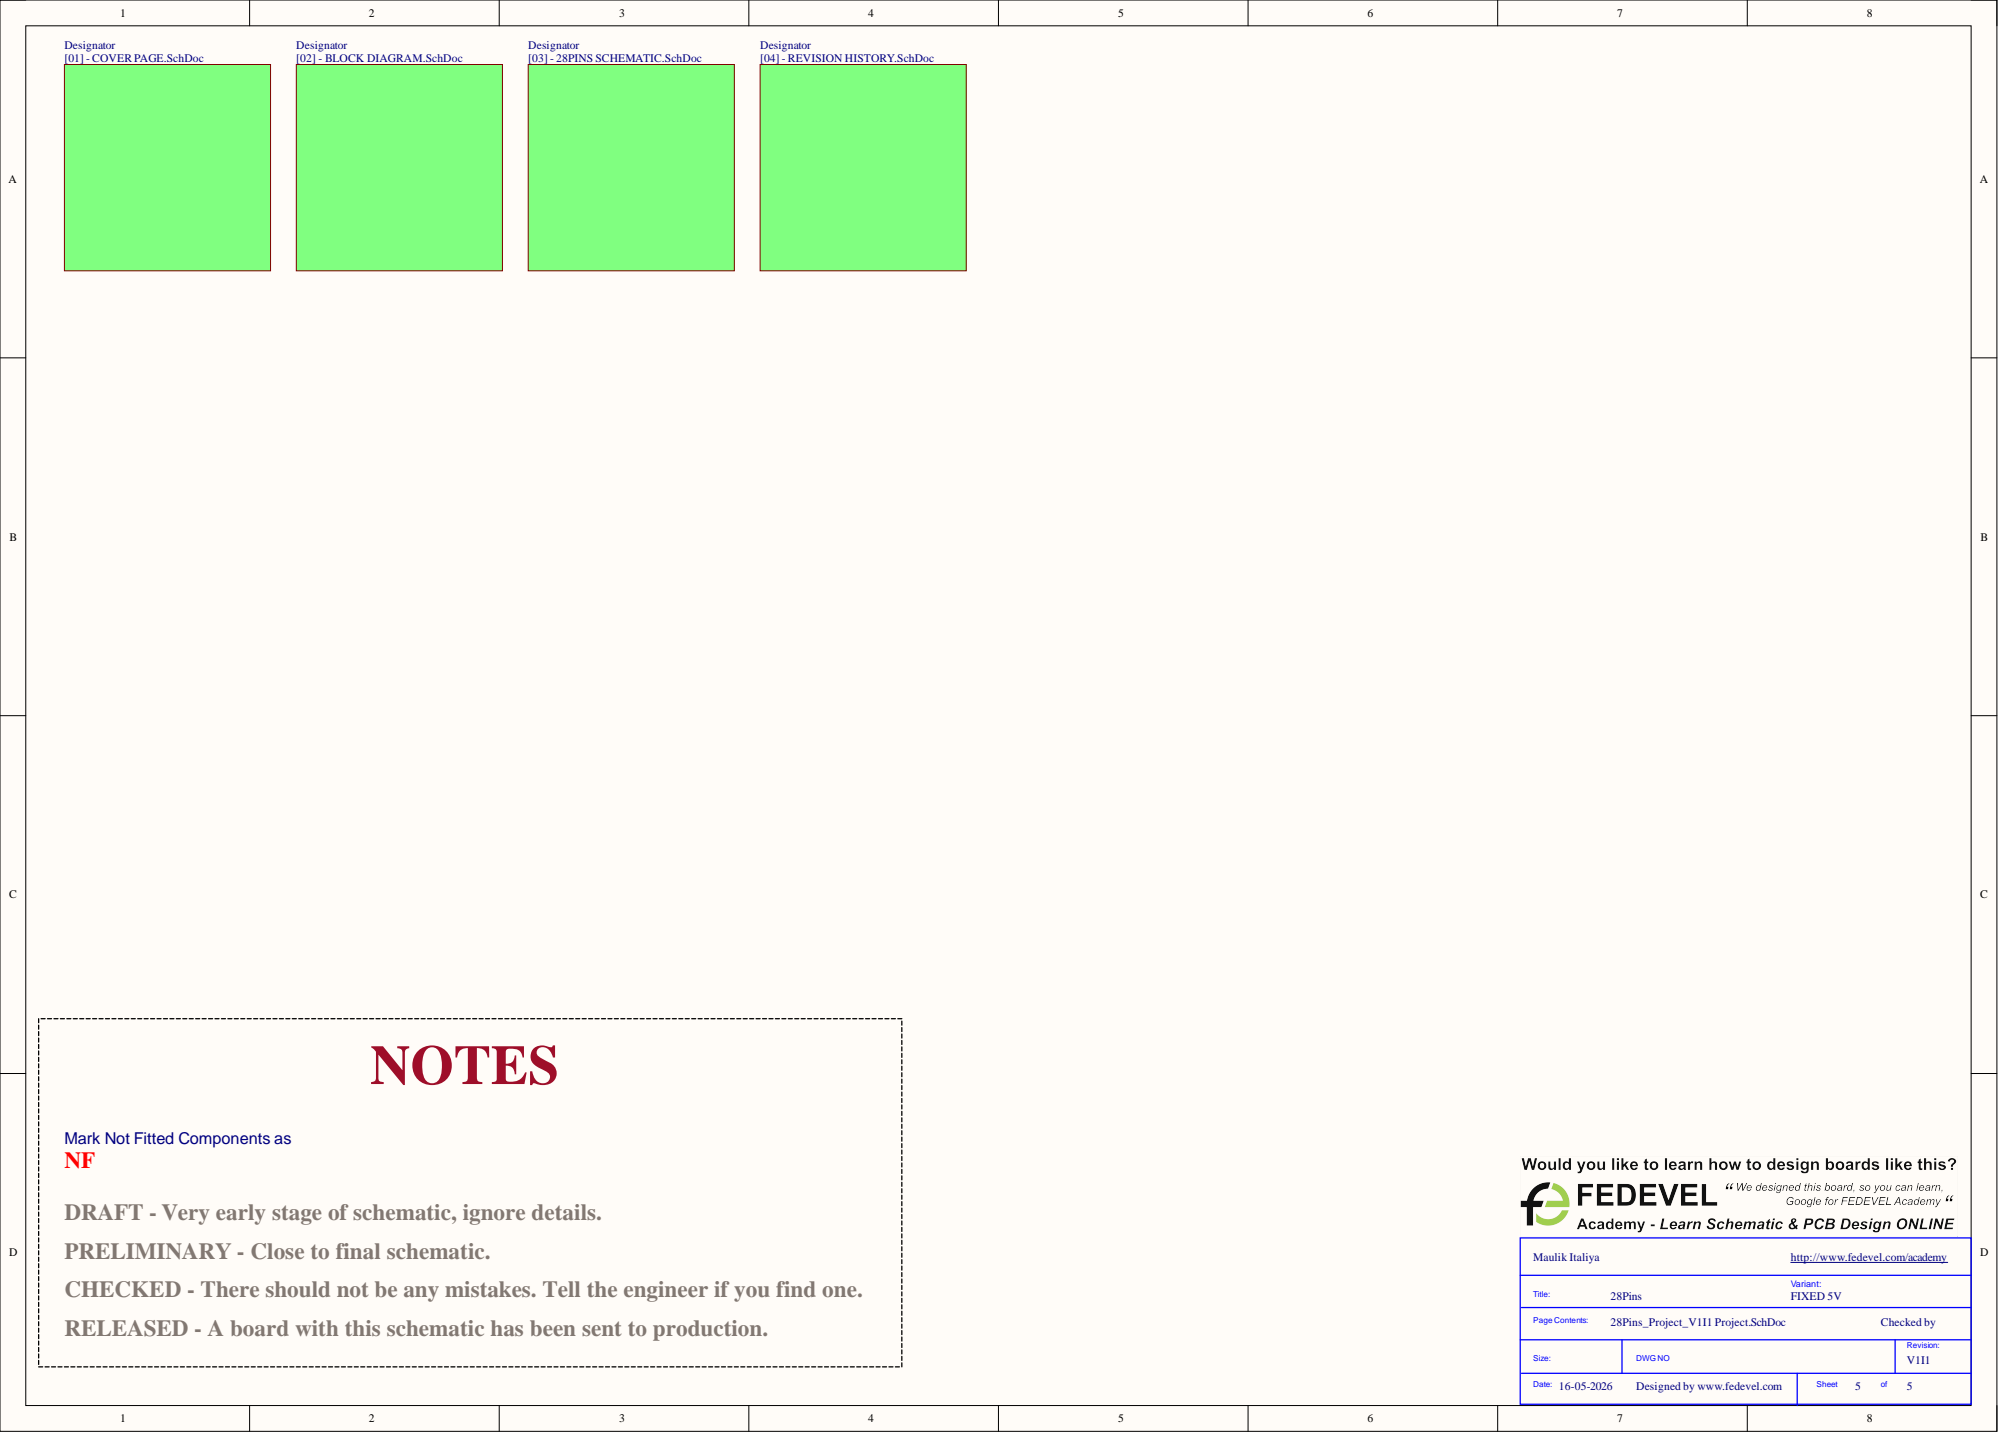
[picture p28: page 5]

Mark Not Fitted Components as

DRAFT - Very early stage of schematic, ignore details.
PRELIMINARY - Close to final schematic.
CHECKED - There should not be any mistakes. Tell the engineer if you find one.
RELEASED - A board with this schematic has been sent to production.

http://www.fedevel.com/academy

Designed by www.fedevel.com

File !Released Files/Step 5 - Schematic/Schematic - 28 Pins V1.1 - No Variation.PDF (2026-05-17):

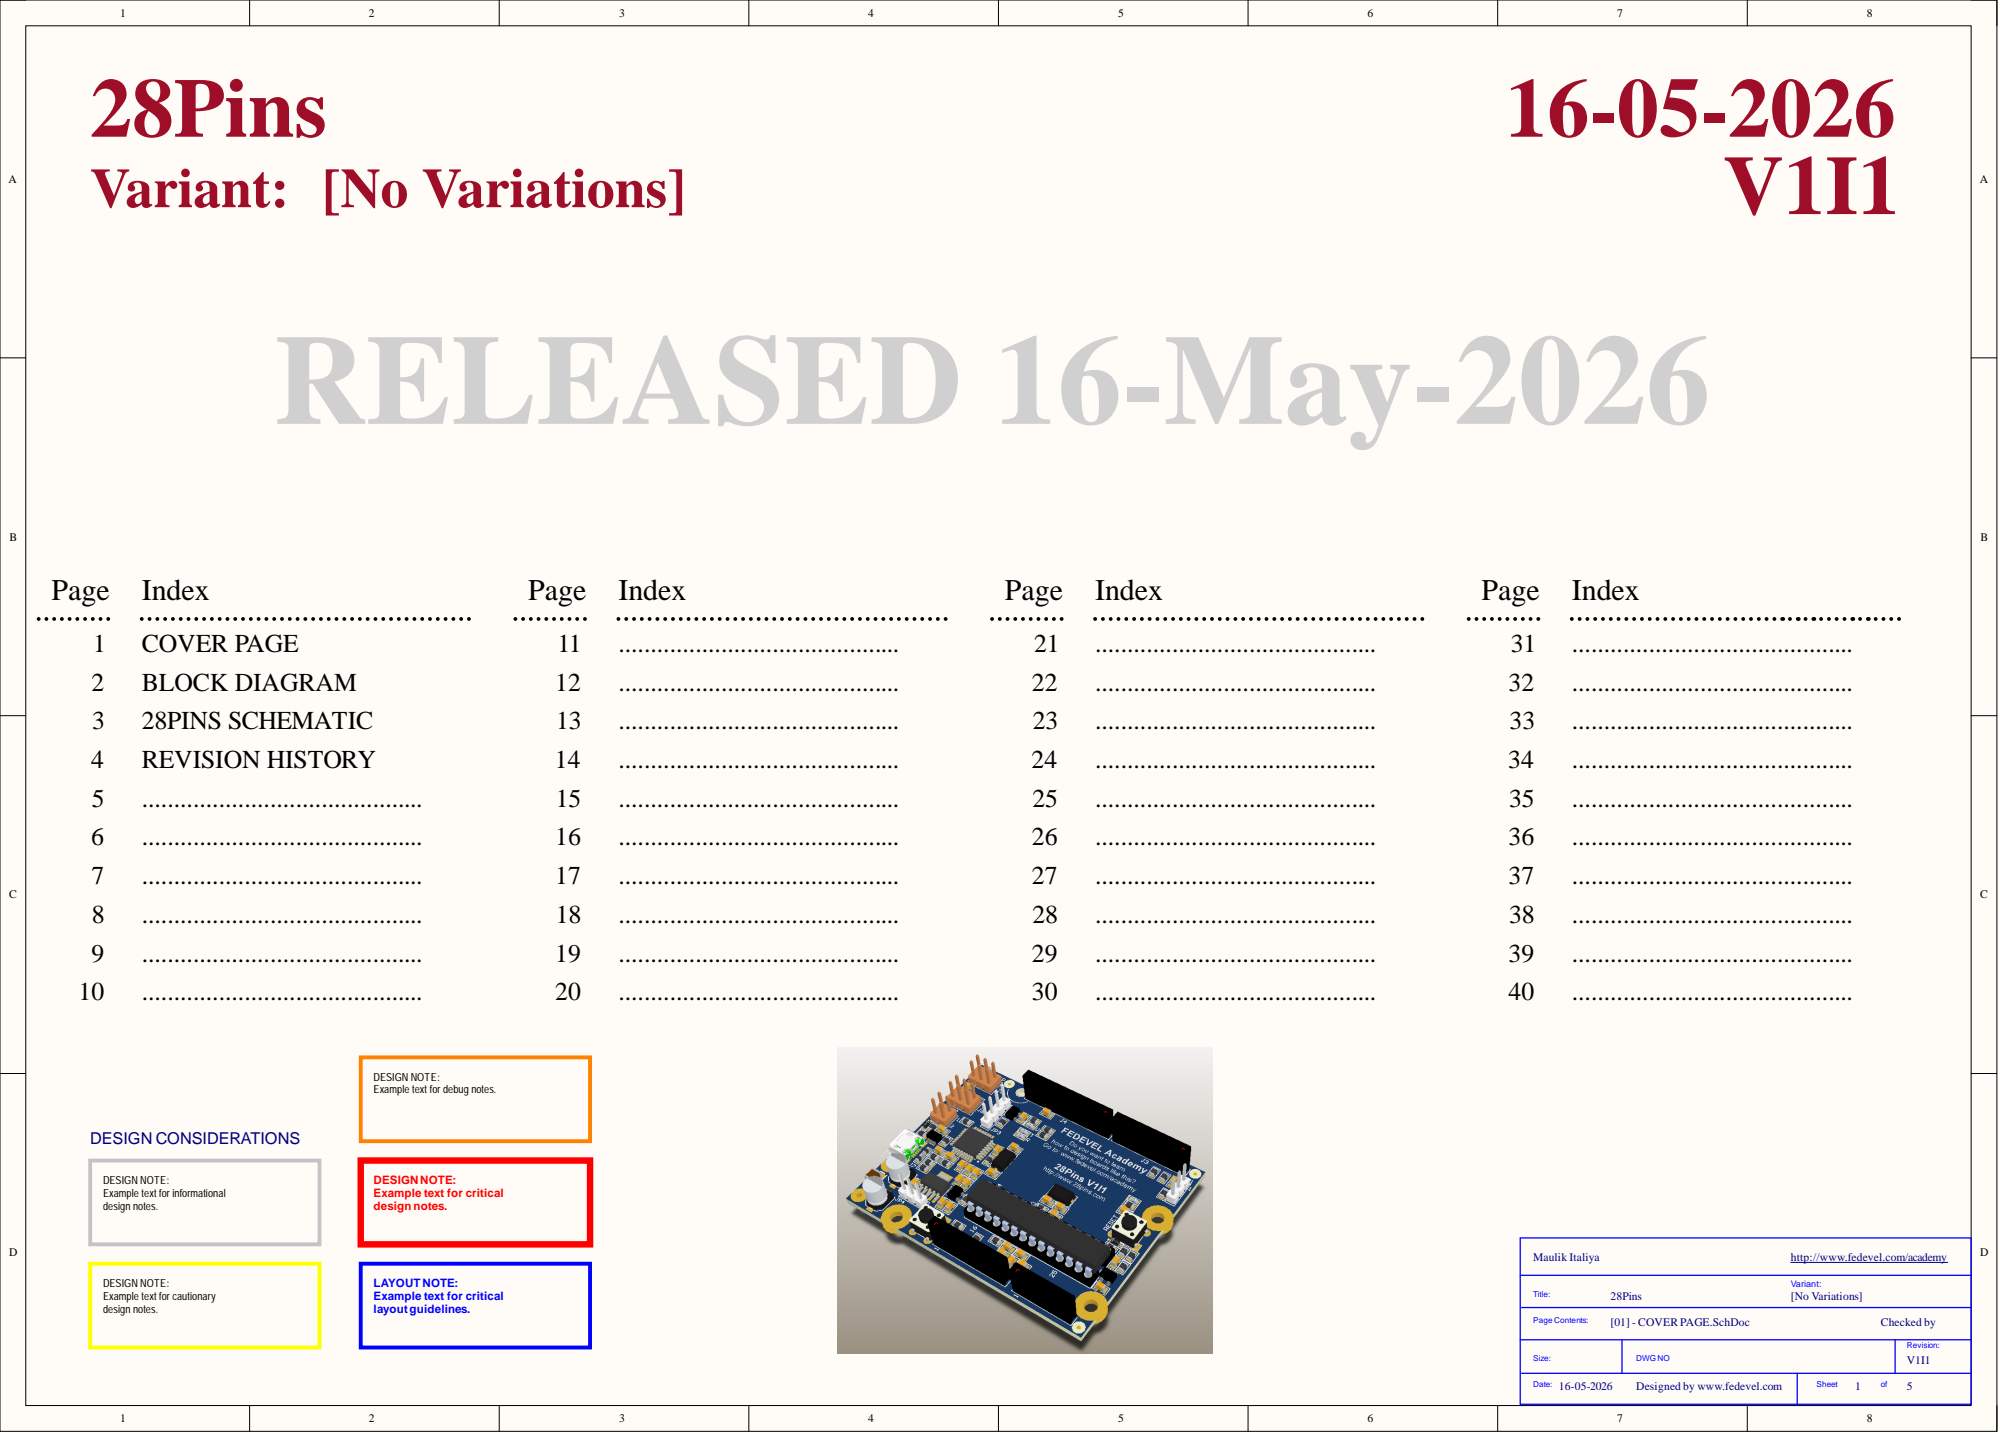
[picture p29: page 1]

DESIGN NOTE:
Example text for debug notes.

Example text for informational
design notes.

Example text for critical

http://www.fedevel.com/academy

Example text for cautionary

LAYOUT NOTE:
layout guidelines.

Size: | DWG NO | Revision: V1I1

Date: 16-05-2026 Designed by www.fedevel.com | Sheet of

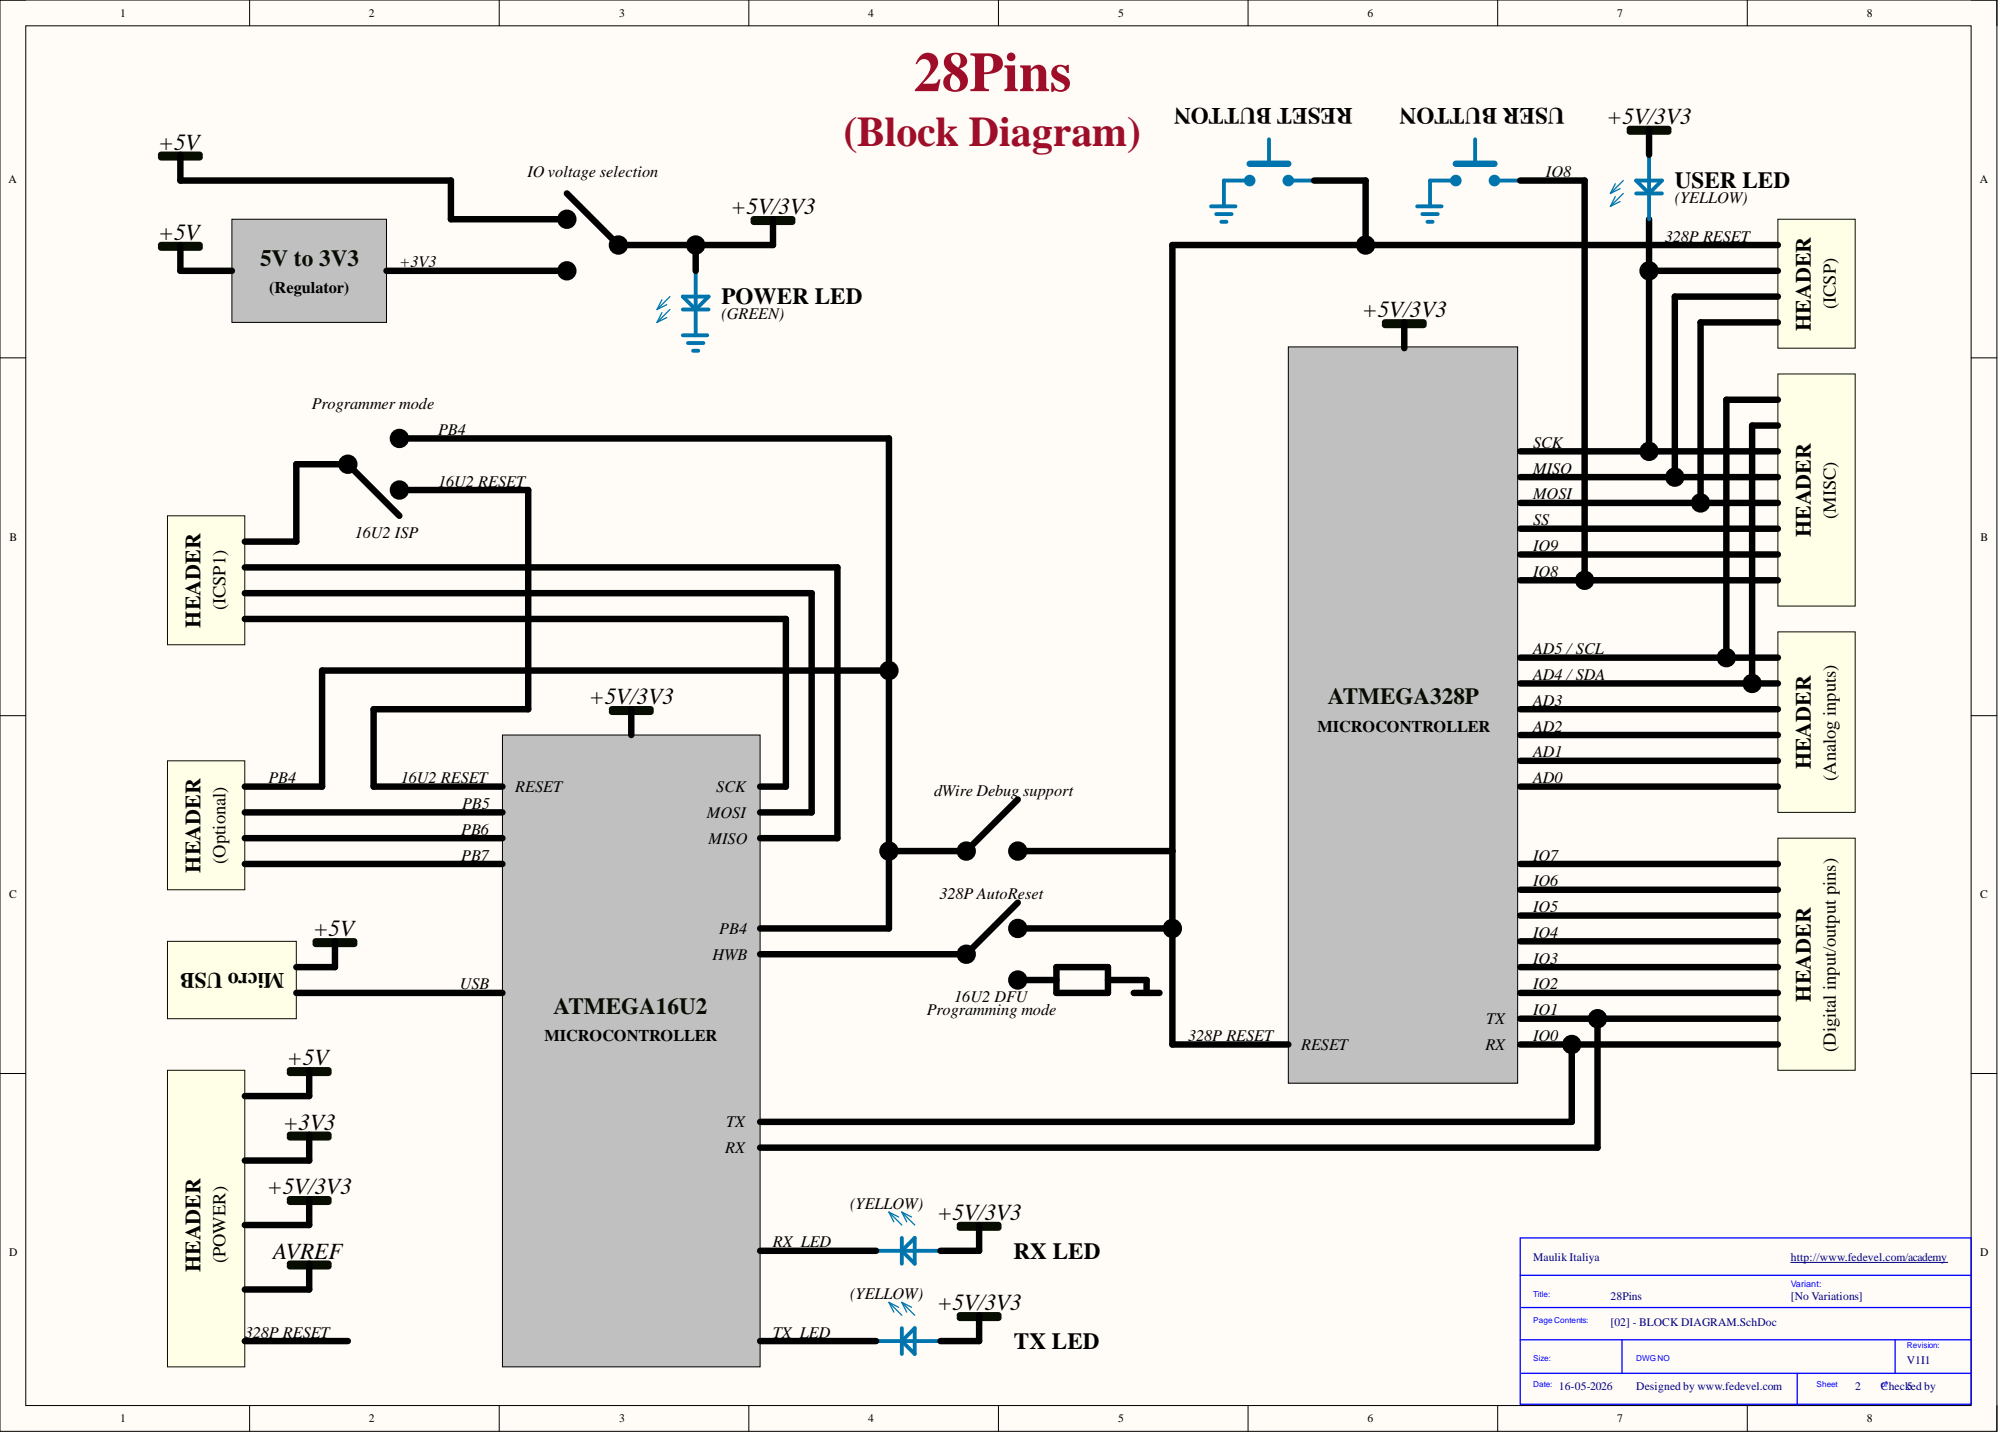
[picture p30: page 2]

MISO
MOSI
SS
IO9
IO8

AD5 / SCL
AD4 / SDA

http://www.fedevel.com/academy


ICSP1 J6

16U2_PB4
16U2_MISO

16U2_16MHZ_XTAL1 | | UGND 28

SCK | MOSI
328P_RESETn

C21 10uF/16V | | AD5/SCL

AD4/SDA

AREF 21 | | SS

(PCINT14/RESET) PC6 1 | | IO8

AD5/SCL

AD2
AD1
AD0
IO4 | 1 1 2 2 3 3 4 4 5 5 6 6 7 7 8 8
IO5

Y1 1M ABM7-16.000MHZ-D2Y-T | (PCINT6/XTAL1/TOSC1) PB6 9

IO2
IO1

GND 22 | IO0



Mark Not Fitted Components as

DRAFT - Very early stage of schematic, ignore details.
PRELIMINARY - Close to final schematic.
CHECKED - There should not be any mistakes. Tell the engineer if you find one.
RELEASED - A board with this schematic has been sent to production.

http://www.fedevel.com/academy

Designed by www.fedevel.com






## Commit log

2026-04-05 Add files via upload
    Initial commit: Arduino-compatible PCB design in Altium (schematic + PCB + outputs)
    [ardino.PrjPcb]
2026-05-17 Add files via upload
    Added schematic symbols and PCB footprint libraries
    [10118193-0001LF--3DModel-STEP-56544.STEP, 1825910-6--3DModel-STEP-418109.STEP, 68000-103HLF--3DModel-STEP-533217.STEP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]
2026-05-17 Add files via upload
    Added component libraries and schematic symbols
2026-05-17 Add files via upload
    Added final PCB layout and routing files
2026-05-17 Add files via upload
    Added schematic File
    [[03] - 28PINS SCHEMATIC.SchDoc]
2026-05-17 Add files via upload
    Added release files for PCB manufacturing
    [28pins_Pcb.GBL, 28pins_Pcb.GBO, 28pins_Pcb.GBS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]
2026-05-17 Add files via upload
    Added the Images of the 3D board

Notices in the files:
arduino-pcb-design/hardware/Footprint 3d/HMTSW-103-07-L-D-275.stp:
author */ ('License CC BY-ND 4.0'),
